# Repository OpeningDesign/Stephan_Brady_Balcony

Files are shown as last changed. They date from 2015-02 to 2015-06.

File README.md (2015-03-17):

Project
==============

Stephan Brady - New Balcony

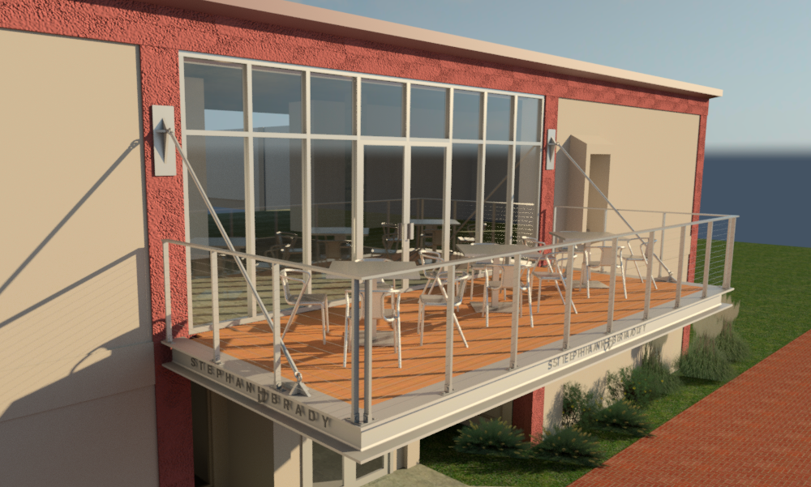
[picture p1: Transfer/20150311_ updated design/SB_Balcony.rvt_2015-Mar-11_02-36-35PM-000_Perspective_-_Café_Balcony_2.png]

============
####In-the-Open

All of [OpeningDesign's](http://openingdesign.com/) projects are conducted out in the open.  That is, during the development of any one project, all team communication and content is hosted [publicly](https://github.com/OpeningDesign) (here on GitHub) and is <a href="#license">open source</a>.

Our [about page](http://openingdesign.com/about/) provides a more nuanced description of this open approach.

============
####License
Per usual, unless otherwise noted, all content associated with [OpeningDesign](http://openingdesign.com) projects is licensed under an open source, 'copyleft' license: 
[Attribution-ShareAlike 4.0 International (CC BY-SA 4.0)](https://creativecommons.org/licenses/by-sa/4.0/).  Attribution to be given to the entire team associated with the project.


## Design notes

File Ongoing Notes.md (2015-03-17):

- (2.27)perforated metal under deck
- (2.27)eliminate under-slung beam
- (2.27)railing to have top cap
- (2.27)decking - angled potentially
- (2.27)lighting
- (2.27)signage
-

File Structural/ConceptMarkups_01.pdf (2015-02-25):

# ntrive

BALCONY | 2015051 SRU | 2/25/15

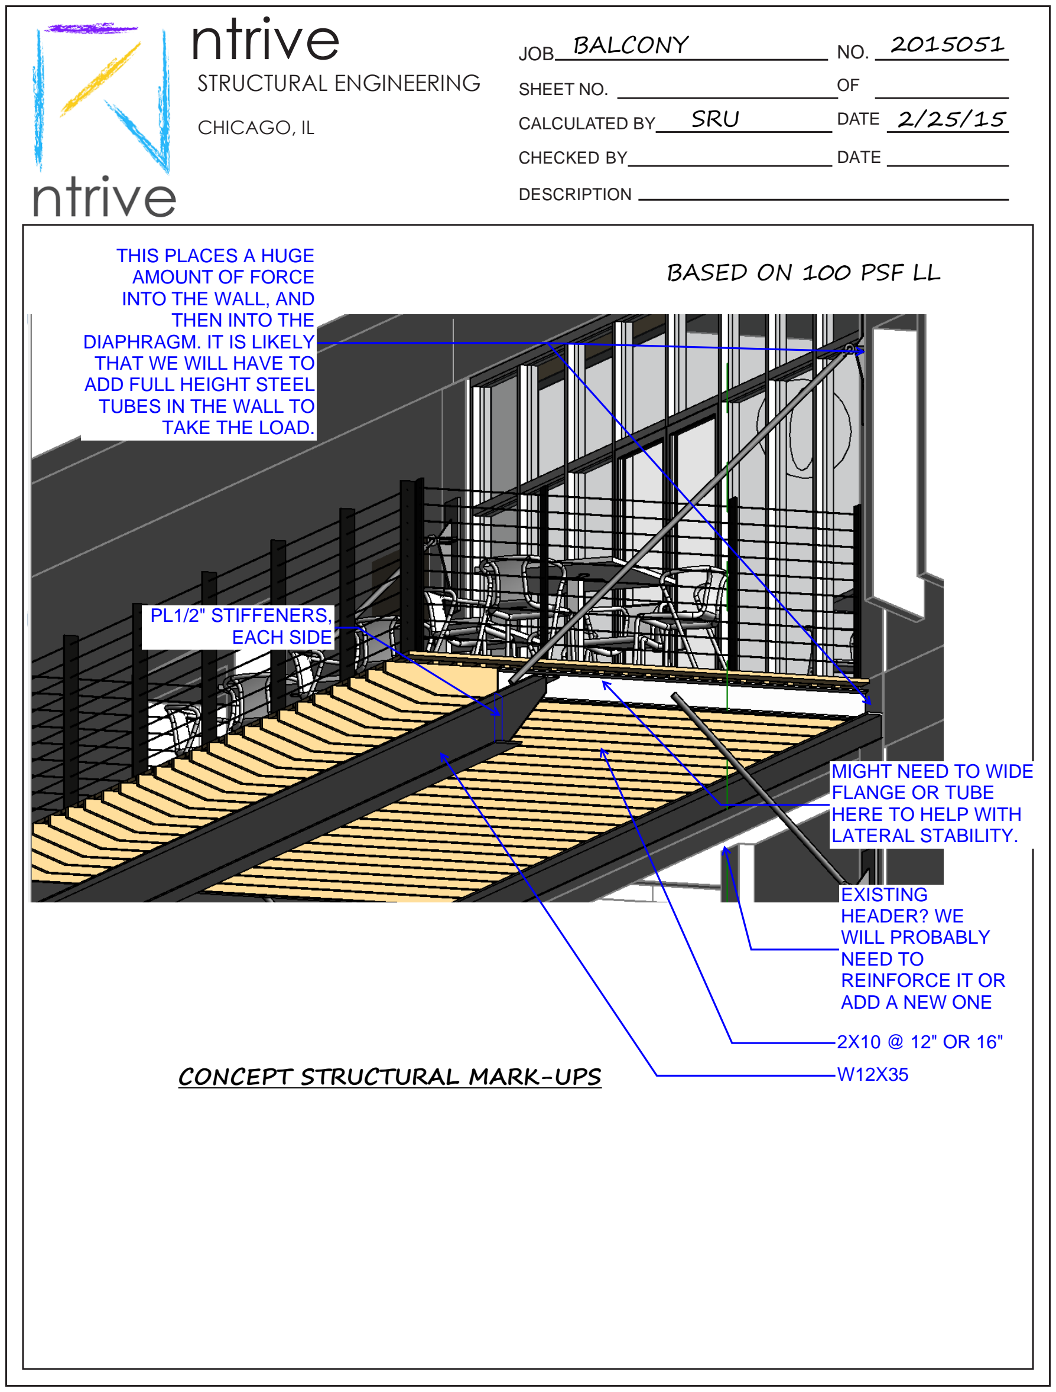
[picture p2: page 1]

STRUCTURAL ENGINEERING

CHICAGO, IL

CHECKED BY

DESCRIPTION

NO.

OF

DATE

DATE

JOB

SHEET NO.

CALCULATED BY

2X10 @ 12" OR 16" W12X35

PL1/2" STIFFENERS,
EACH SIDE

EXISTING
HEADER? WE
WILL PROBABLY
NEED TO
REINFORCE IT OR
ADD A NEW ONE

THIS PLACES A HUGE
AMOUNT OF FORCE
INTO THE WALL, AND
THEN INTO THE
DIAPHRAGM. IT IS LIKELY
THAT WE WILL HAVE TO
ADD FULL HEIGHT STEEL
TUBES IN THE WALL TO
TAKE THE LOAD.

# CONCEPT STRUCTURAL MARK-UPS

MIGHT NEED TO WIDE
FLANGE OR TUBE
HERE TO HELP WITH

LATERAL STABILITY. BASED ON 100 PSF LL

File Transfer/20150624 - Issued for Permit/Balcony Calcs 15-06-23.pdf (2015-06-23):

# Stephan & Brady Balcony

# 1850 Hoffman St

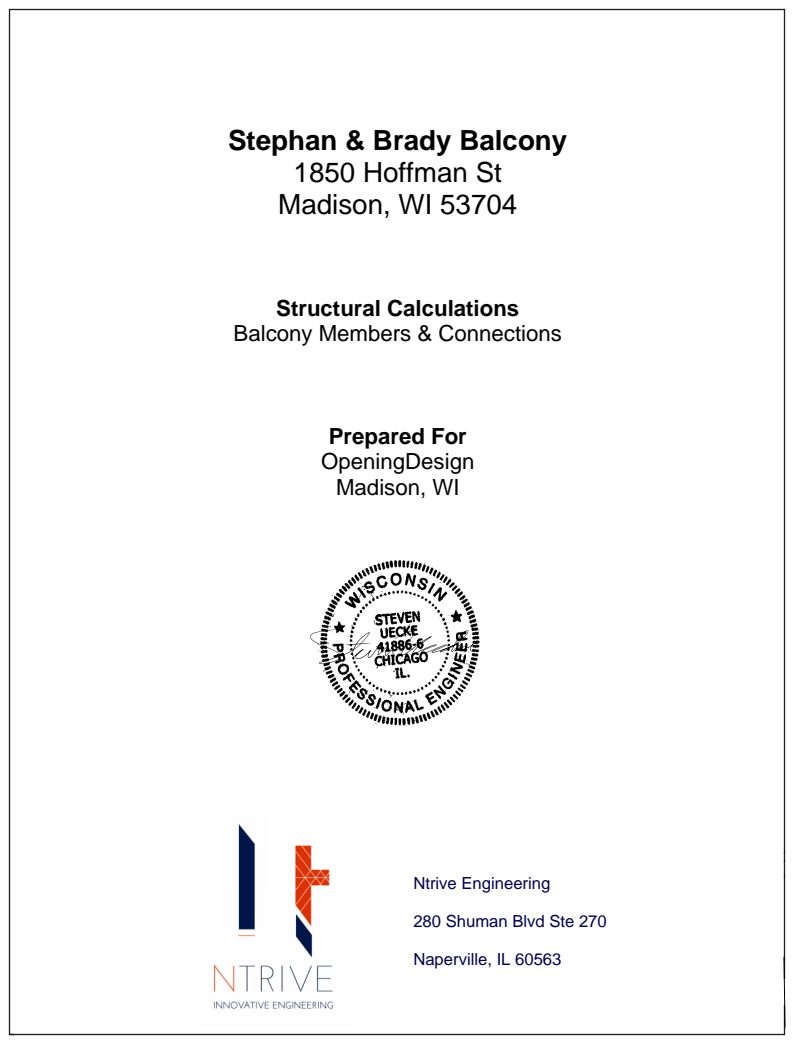
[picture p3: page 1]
Madison, WI 53704; Prepared For OpeningDesign Madison, WI

Structural Calculations
Balcony Members & Connections

Ntrive Engineering
280 Shuman Blvd Ste 270
Naperville, IL 60563

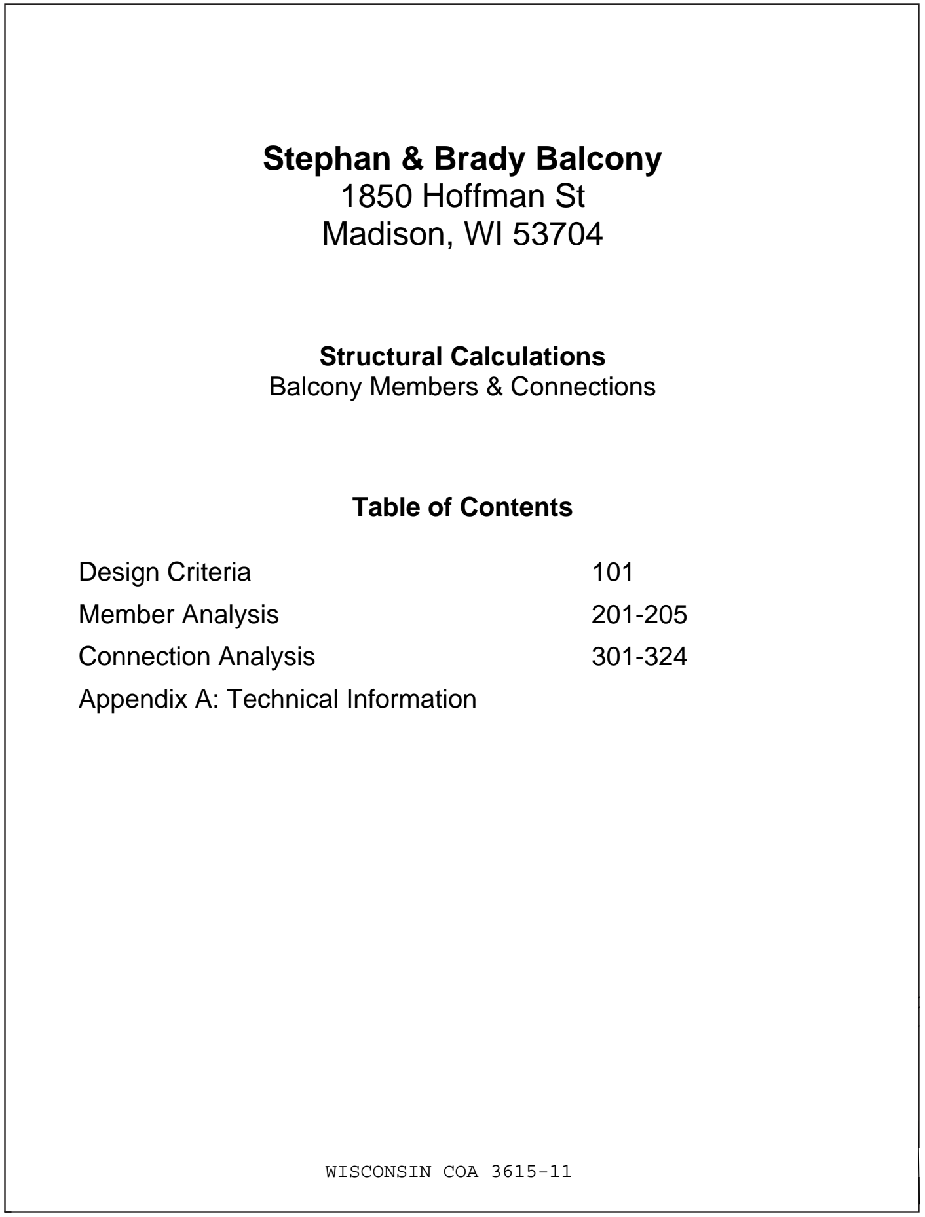
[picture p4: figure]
Stephan & Brady Balcony 1850 Hoffman St Madison, WI 53704; Structural Calculations Balcony Members & Connections; Table of Contents; Design Criteria Member Analysis Connection Analysis Appendix A: Technical Information; WISCONSIN COA 3615-11

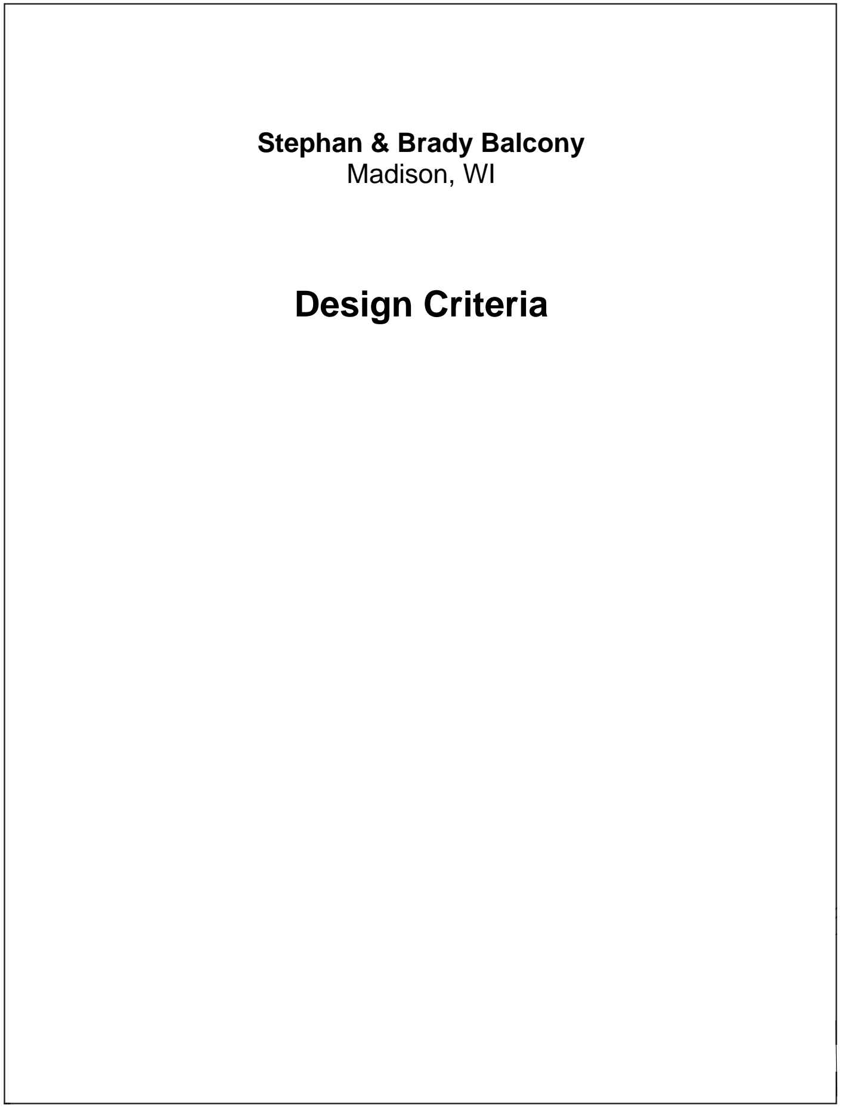
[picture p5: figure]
Stephan & Brady Balcony Madison, WI; Design Criteria

# Ntrive Engineering

# 280 Shuman Blvd Ste 270

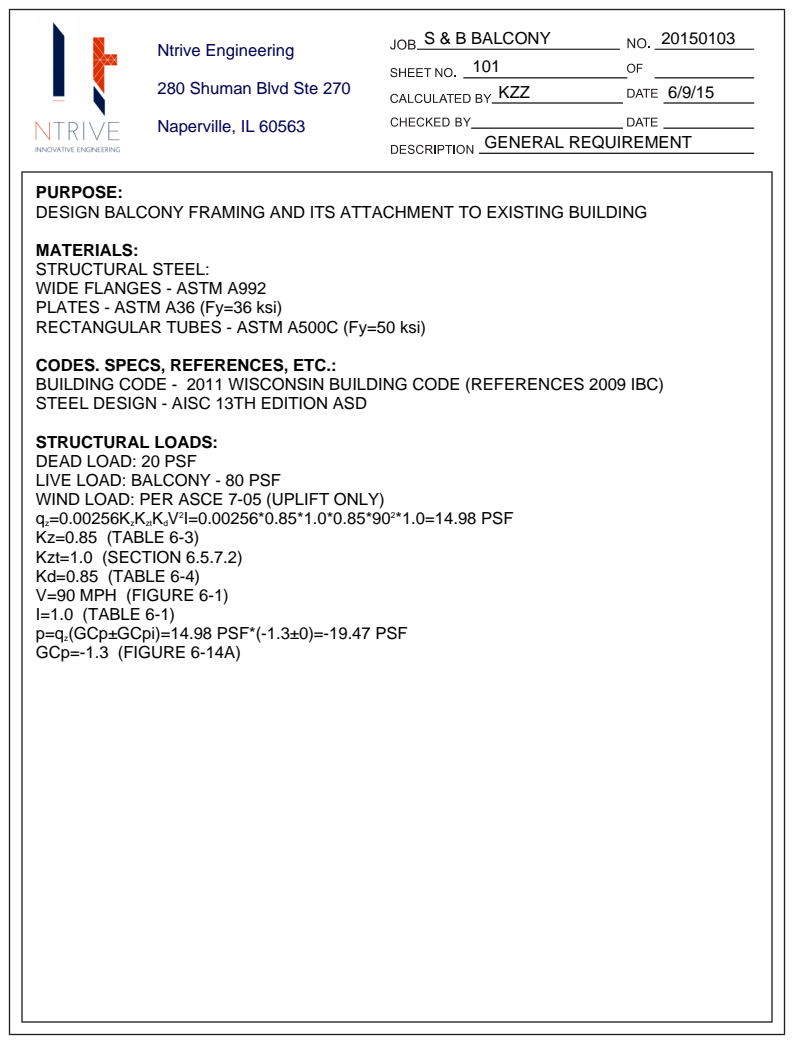
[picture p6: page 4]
Naperville, IL 60563; S & B BALCONY; 20150103 KZZ; 6/9/15 GENERAL REQUIREMENT; *1.0=14.98 PSF

PURPOSE:
DESIGN BALCONY FRAMING AND ITS ATTACHMENT TO EXISTING BUILDING
MATERIALS:
STRUCTURAL STEEL:
WIDE FLANGES - ASTM A992
PLATES - ASTM A36 (Fy=36 ksi)
RECTANGULAR TUBES - ASTM A500C (Fy=50 ksi)
CODES. SPECS, REFERENCES, ETC.:
BUILDING CODE - 2011 WISCONSIN BUILDING CODE (REFERENCES 2009 IBC)
STEEL DESIGN - AISC 13TH EDITION ASD
STRUCTURAL LOADS:
DEAD LOAD: 20 PSF
LIVE LOAD: BALCONY - 80 PSF
WIND LOAD: PER ASCE 7-05 (UPLIFT ONLY)
qz=0.00256KzKztKdV
Kz=0.85 (TABLE 6-3)
Kzt=1.0 (SECTION 6.5.7.2)
Kd=0.85 (TABLE 6-4)
V=90 MPH (FIGURE 6-1)
I=1.0 (TABLE 6-1)
p=qz(GCp±GCpi)=14.98 PSF*(-1.3±0)=-19.47 PSF
GCp=-1.3 (FIGURE 6-14A)

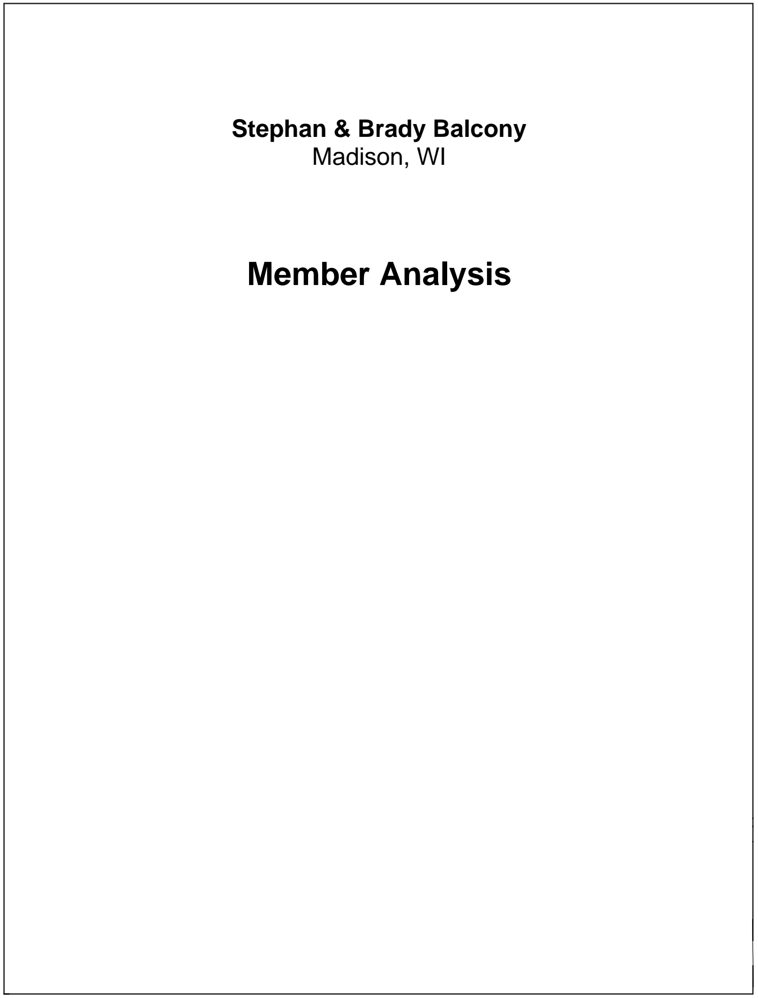
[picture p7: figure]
Stephan & Brady Balcony Madison, WI; Member Analysis

# Ntrive Engineering

# 280 Shuman Blvd Ste 270

PRE-DRILLED GALVANIZED
STEEL (W10X39) W - SECTION

FIRE-RATED LUMBER
SIZE AND O.C. SPACING T.B.D.

COMPOSITE DECKING ABOVE

CHECK BENDING STRENGTH OF WIDE FLANGE BEAM:
Wd=20 PSF*11'/2=110 PLF
Wl=80 PSF*11'/2=440 PLF
Wt=110 PLF+440 PLF=550 PLF
Mact=Wt*L²
Mall=117 FT*K > 30.8 FT*K, OK (AISC TABLE 3-6)
CHECK DEFLECTION OF WIDE FLANGE BEAM:
Δ=(5*Wt*L⁴⁾/(384*E*I)=(5*550 PLF*(21'-2")⁴
Δall=L/240=21'-2"/240=1.058" > 0.409", OK
PROVIDE W10x39

# Ntrive Engineering

# 280 Shuman Blvd Ste 270

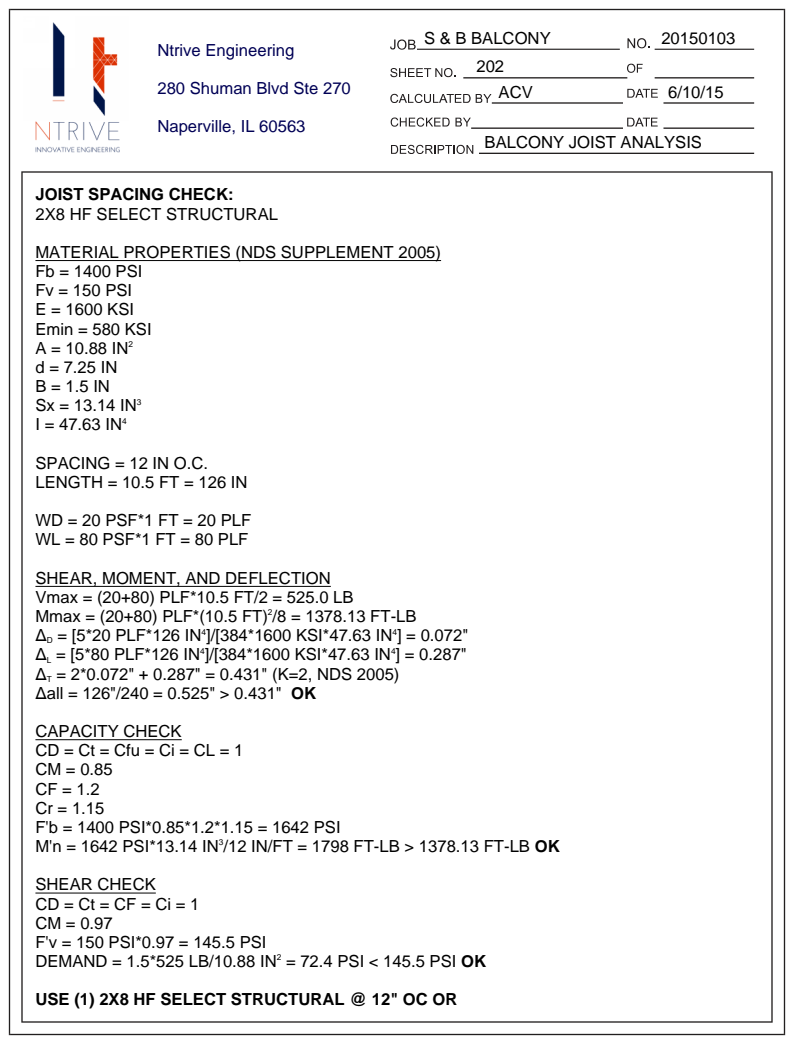
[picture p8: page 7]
Naperville, IL 60563; S & B BALCONY; 20150103 ACV; 6/10/15 BALCONY JOIST ANALYSIS; /8 = 1378.13 FT-LB ]/[384*1600 KSI*47.63 IN⁴; ]/[384*1600 KSI*47.63 IN⁴

USE (1) 2X8 HF SELECT STRUCTURAL @ 12" OC OR 202

JOIST SPACING CHECK:
2X8 HF SELECT STRUCTURAL

MATERIAL PROPERTIES (NDS SUPPLEMENT 2005)
Fb = 1400 PSI
Fv = 150 PSI
E = 1600 KSI
Emin = 580 KSI
A = 10.88 IN²
Sx = 13.14 IN³
I = 47.63 IN⁴

SPACING = 12 IN O.C.
LENGTH = 10.5 FT = 126 IN

WD = 20 PSF*1 FT = 20 PLF
WL = 80 PSF*1 FT = 80 PLF

SHEAR, MOMENT, AND DEFLECTION
Vmax = (20+80) PLF*10.5 FT/2 = 525.0 LB
Mmax = (20+80) PLF*(10.5 FT)²
ΔD = [5*20 PLF*126 IN⁴
ΔL = [5*80 PLF*126 IN⁴
ΔT = 2*0.072" + 0.287" = 0.431" (K=2, NDS 2005)
Δall = 126"/240 = 0.525" > 0.431" OK

CAPACITY CHECK
CD = Ct = Cfu = Ci = CL = 1
F'b = 1400 PSI*0.85*1.2*1.15 = 1642 PSI
M'n = 1642 PSI*13.14 IN³

SHEAR CHECK
F'v = 150 PSI*0.97 = 145.5 PSI
DEMAND = 1.5*525 LB/10.88 IN²

= 72.4 PSI < 145.5 PSI OK

# Ntrive Engineering

# 280 Shuman Blvd Ste 270

JOIST SPACING CHECK:

MATERIAL PROPERTIES (NDS SUPPLEMENT 2005)
Fb = 850 PSI
Fv = 150 PSI
E = 1300 KSI
Emin = 470 KSI
A = 10.88 IN²
Sx = 13.14 IN³
I = 47.63 IN⁴

SPACING = 12 IN O.C.
LENGTH = 10.5 FT = 126 IN

WD = 20 PSF*1 FT = 20 PLF
WL = 80 PSF*1 FT = 80 PLF

SHEAR, MOMENT, AND DEFLECTION
Vmax = (20+80) PLF*10.5 FT/2 = 525.0 LB
Mmax = (20+80) PLF*(10.5 FT)²
ΔD = [5*20 PLF*126 IN⁴
ΔL = [5*80 PLF*126 IN⁴
ΔT = (2*0.088" + 0.353")/2 = 0.265" (K=2, NDS 2005)
Δall = 126"/240 = 0.525" > 0.265" OK

CAPACITY CHECK
CD = CM = Ct = Cfu = Ci = CL = 1
F'b = 850 PSI*1.2*1.15 = 1173 PSI
M'n = 2*1173 PSI*13.14 IN³

SHEAR CHECK
F'v = 150 PSI*0.97 = 145.5 PSI
DEMAND = 1.5*525 LB/2*10.88 IN²
USE (2) 2X8 HF NO.2 OR BETTER @ 12" OC

= 36.2 PSI < 145.5 PSI OK

# Ntrive Engineering

# 280 Shuman Blvd Ste 270

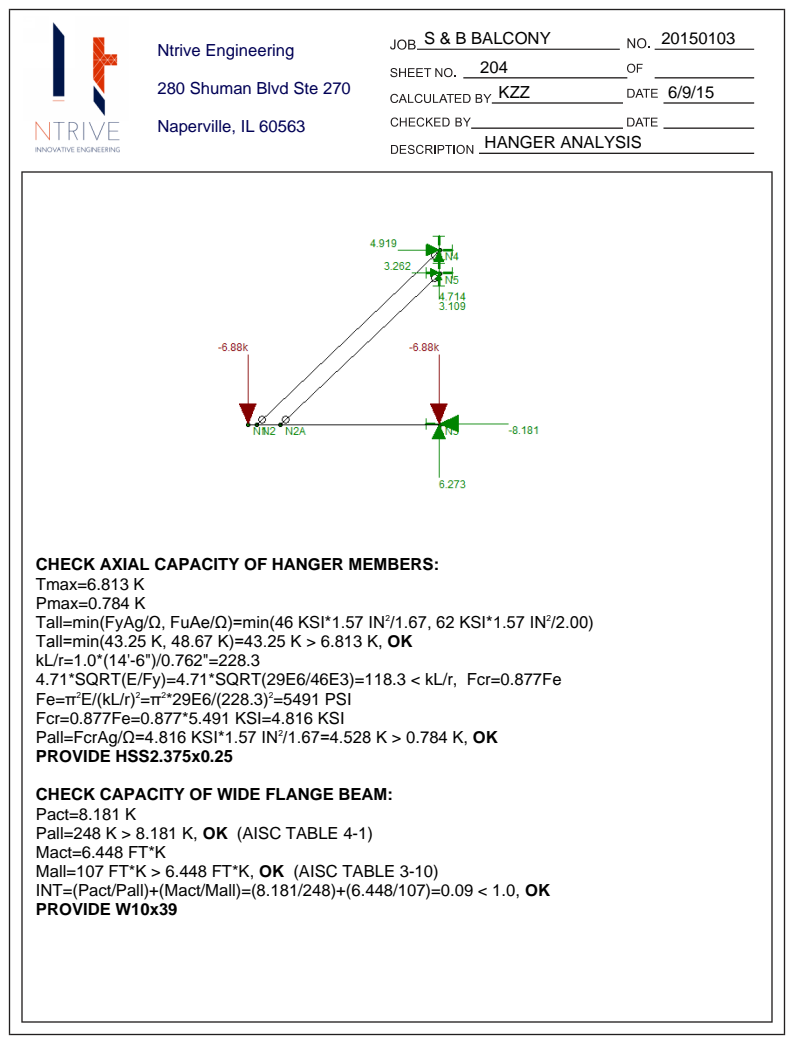
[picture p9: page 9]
Naperville, IL 60563; S & B BALCONY; 20150103 KZZ; 6/9/15 HANGER ANALYSIS; /1.67, 62 KSI*1.57 IN²; *29E6/(228.3)²=5491 PSI

CHECK AXIAL CAPACITY OF HANGER MEMBERS:
Tmax=6.813 K
Pmax=0.784 K
Tall=min(FyAg/Ω, FuAe/Ω)=min(46 KSI*1.57 IN²
Tall=min(43.25 K, 48.67 K)=43.25 K > 6.813 K, OK
4.71*SQRT(E/Fy)=4.71*SQRT(29E6/46E3)=118.3 < kL/r, Fcr=0.877Fe
Fcr=0.877Fe=0.877*5.491 KSI=4.816 KSI
Pall=FcrAg/Ω=4.816 KSI*1.57 IN²
PROVIDE HSS2.375x0.25
CHECK CAPACITY OF WIDE FLANGE BEAM:
Pact=8.181 K
Pall=248 K > 8.181 K, OK (AISC TABLE 4-1)
Mact=6.448 FT*K
Mall=107 FT*K > 6.448 FT*K, OK (AISC TABLE 3-10)
INT=(Pact/Pall)+(Mact/Mall)=(8.181/248)+(6.448/107)=0.09 < 1.0, OK
PROVIDE W10x39

# Ntrive Engineering

# 280 Shuman Blvd Ste 270

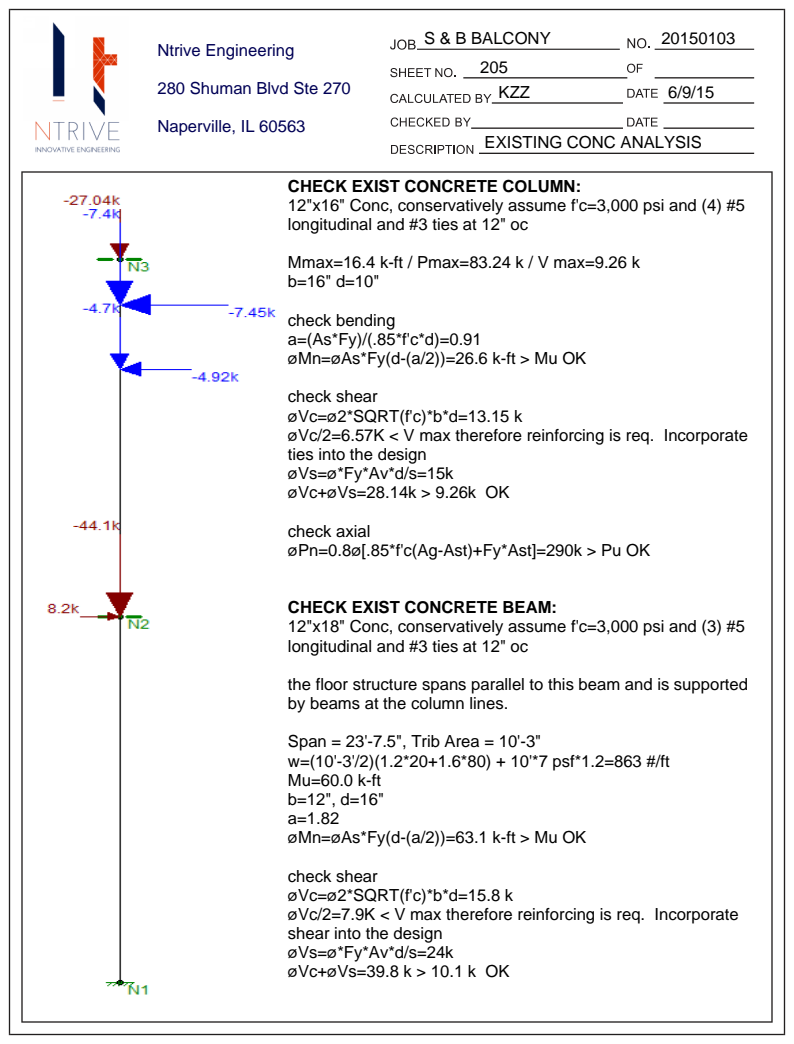
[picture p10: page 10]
Naperville, IL 60563; S & B BALCONY; 20150103 KZZ; 6/9/15 EXISTING CONC ANALYSIS

CHECK EXIST CONCRETE COLUMN:
12"x16" Conc, conservatively assume f'c=3,000 psi and (4) #5
longitudinal and #3 ties at 12" oc
Mmax=16.4 k-ft / Pmax=83.24 k / V max=9.26 k
check bending
øMn=øAs*Fy(d-(a/2))=26.6 k-ft > Mu OK
check shear
øVc=ø2*SQRT(f'c)*b*d=13.15 k
øVc/2=6.57K < V max therefore reinforcing is req. Incorporate
ties into the design
øVs=ø*Fy*Av*d/s=15k
øVc+øVs=28.14k > 9.26k OK
check axial
øPn=0.8ø[.85*f'c(Ag-Ast)+Fy*Ast]=290k > Pu OK

CHECK EXIST CONCRETE BEAM:
12"x18" Conc, conservatively assume f'c=3,000 psi and (3) #5
the floor structure spans parallel to this beam and is supported
by beams at the column lines.
Span = 23'-7.5", Trib Area = 10'-3"
w=(10'-3'/2)(1.2*20+1.6*80) + 10'*7 psf*1.2=863 #/ft
øMn=øAs*Fy(d-(a/2))=63.1 k-ft > Mu OK
øVc=ø2*SQRT(f'c)*b*d=15.8 k
øVc/2=7.9K < V max therefore reinforcing is req. Incorporate
shear into the design
øVs=ø*Fy*Av*d/s=24k
øVc+øVs=39.8 k > 10.1 k OK

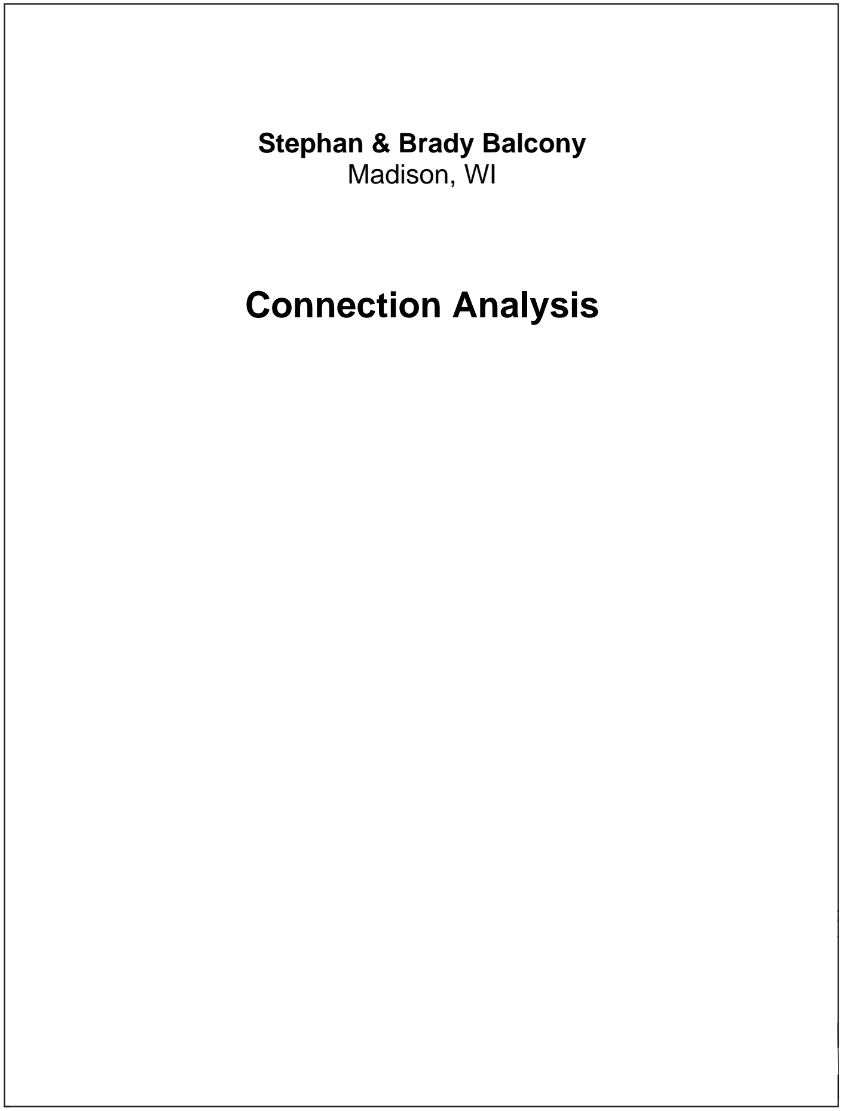
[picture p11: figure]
Stephan & Brady Balcony Madison, WI; Connection Analysis

# Ntrive Engineering

# 280 Shuman Blvd Ste 270

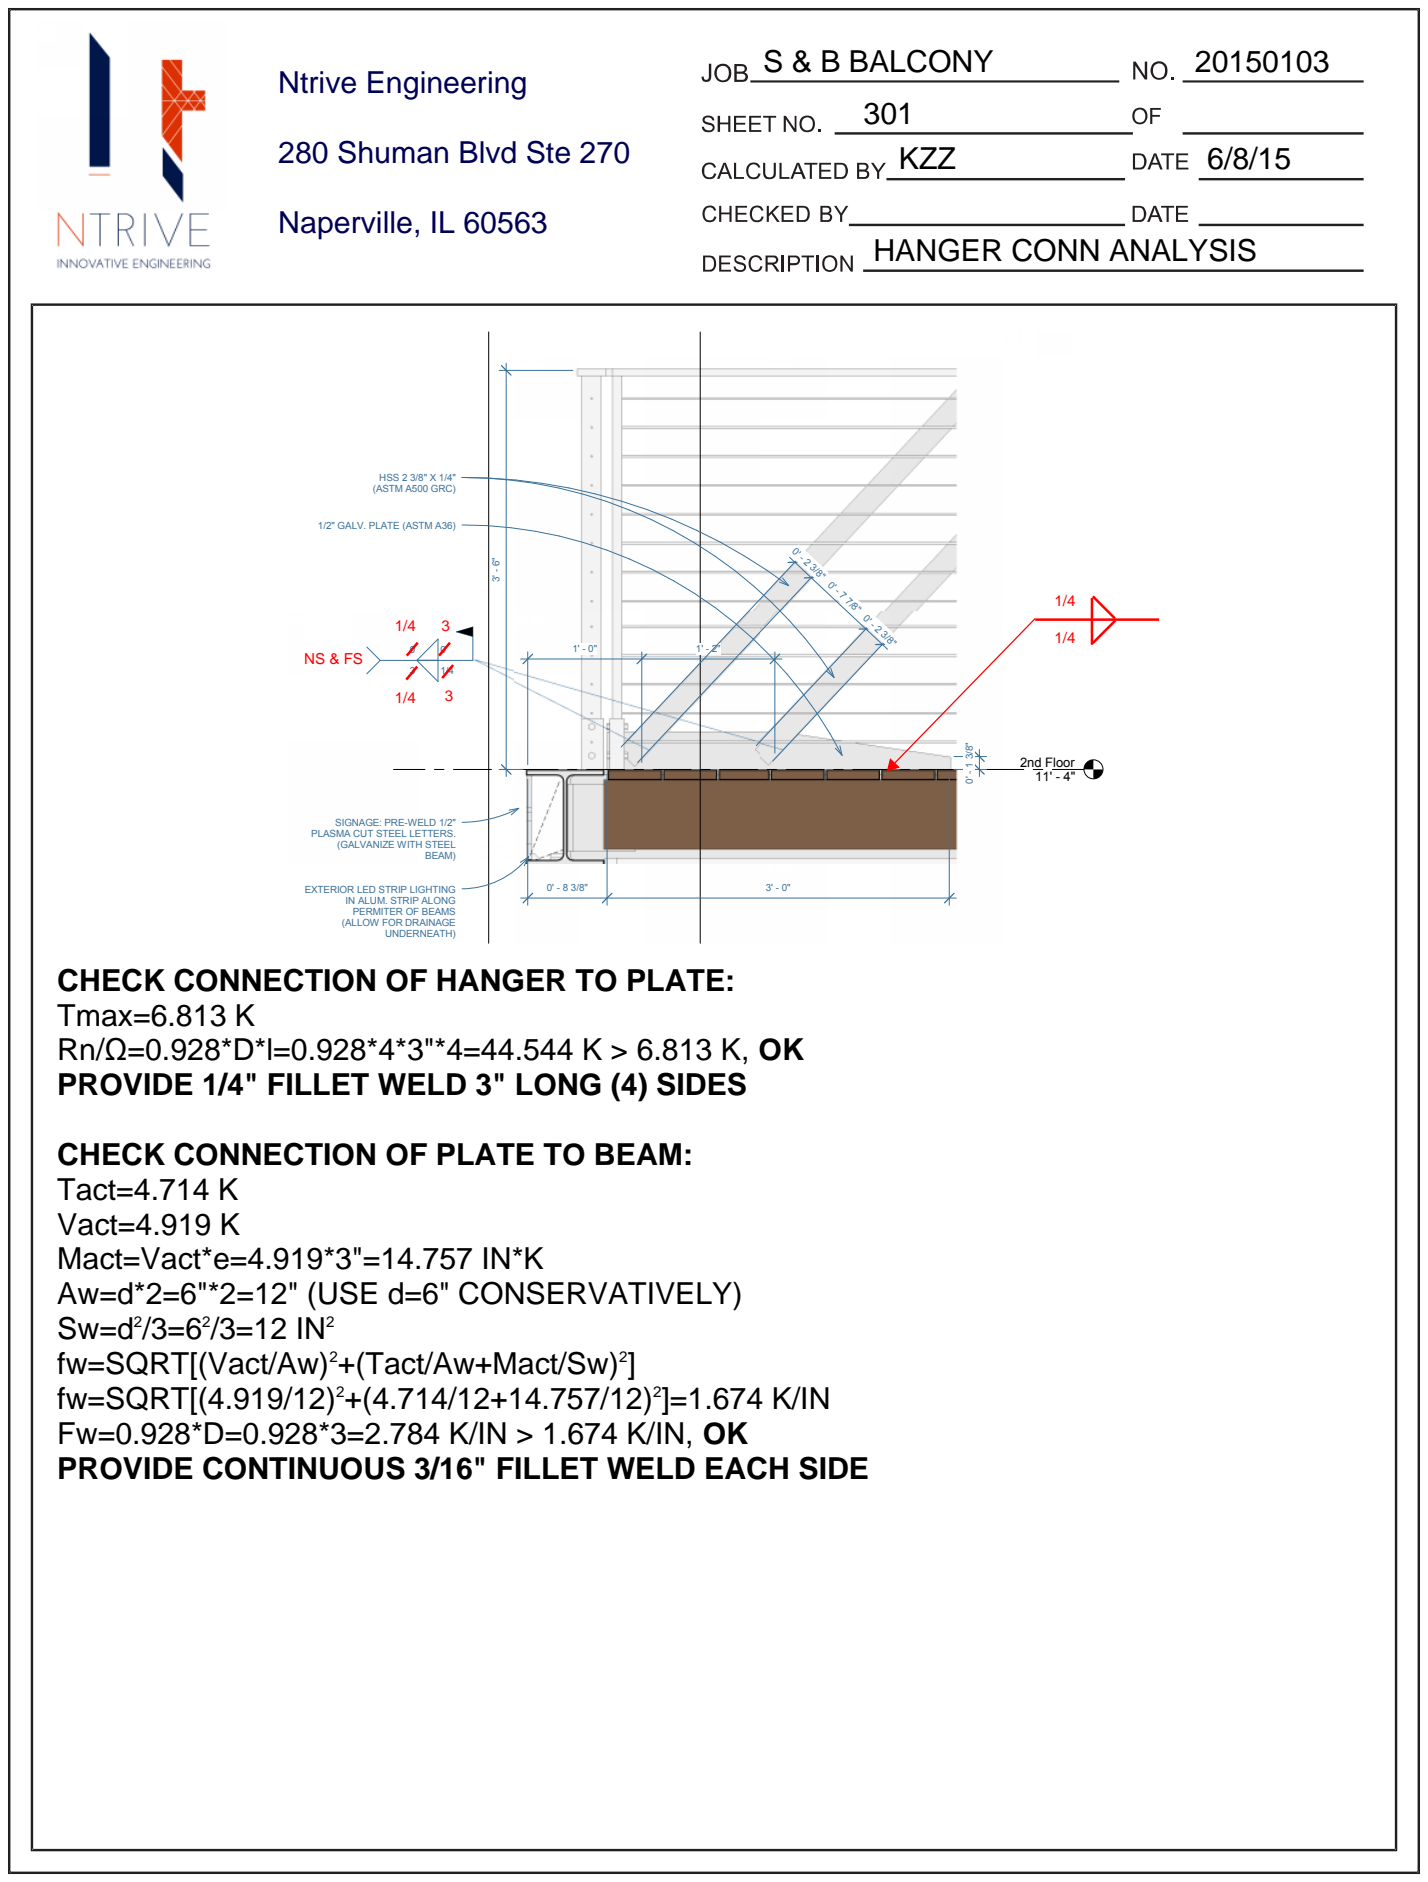
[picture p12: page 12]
Naperville, IL 60563; S & B BALCONY; 20150103 KZZ; 6/8/15 HANGER CONN ANALYSIS; /3=12 IN²; 2nd Floor 11' - 4"; HSS 2 3/8" X 1/4" (ASTM A500 GRC)

1/2" GALV. PLATE (ASTM A36)

SIGNAGE: PRE-WELD 1/2" PLASMA CUT STEEL LETTERS.

(GALVANIZE WITH STEEL BEAM)

EXTERIOR LED STRIP LIGHTING

IN ALUM. STRIP ALONG
PERMITER OF BEAMS
(ALLOW FOR DRAINAGE UNDERNEATH)

CHECK CONNECTION OF HANGER TO PLATE:
Tmax=6.813 K
PROVIDE 1/4" FILLET WELD 3" LONG (4) SIDES
CHECK CONNECTION OF PLATE TO BEAM:
Tact=4.714 K
Vact=4.919 K
Mact=Vact*e=4.919*3"=14.757 IN*K
Aw=d*2=6"*2=12" (USE d=6" CONSERVATIVELY)
fw=SQRT[(Vact/Aw)²+(Tact/Aw+Mact/Sw)²
fw=SQRT[(4.919/12)²+(4.714/12+14.757/12)²
PROVIDE CONTINUOUS 3/16" FILLET WELD EACH SIDE

# Ntrive Engineering

# 280 Shuman Blvd Ste 270

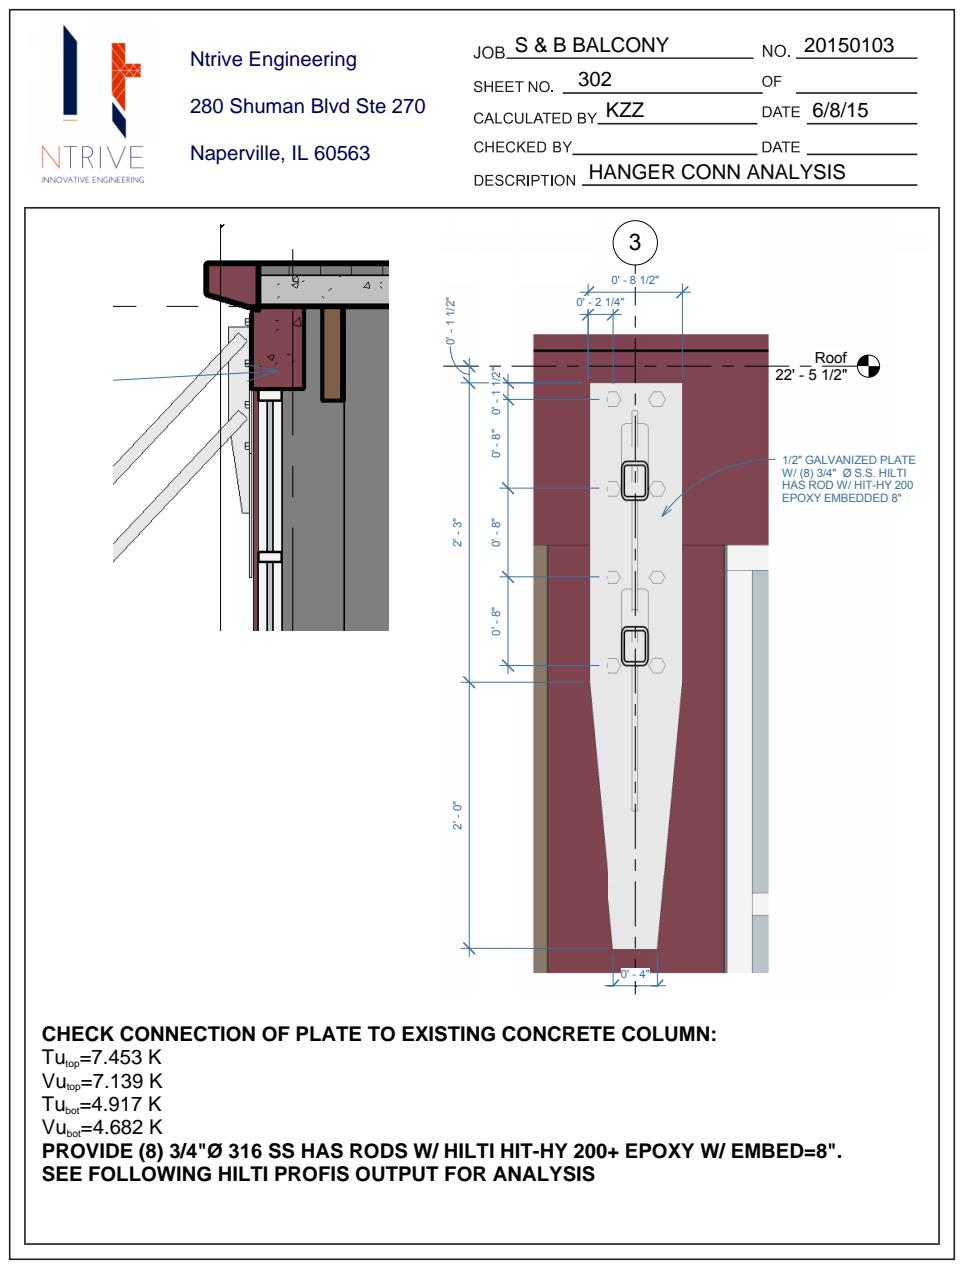
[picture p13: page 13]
Naperville, IL 60563; S & B BALCONY; 20150103 KZZ; 6/8/15 HANGER CONN ANALYSIS; Roof 22' - 5 1/2"

1/2" GALVANIZED PLATE
W/ (8) 3/4" Ø S.S. HILTI
HAS ROD W/ HIT-HY 200
EPOXY EMBEDDED 8"

CHECK CONNECTION OF PLATE TO EXISTING CONCRETE COLUMN:
Tutop=7.453 K
Vutop=7.139 K
Tubot=4.917 K
Vubot=4.682 K
PROVIDE (8) 3/4"Ø 316 SS HAS RODS W/ HILTI HIT-HY 200+ EPOXY W/ EMBED=8".
SEE FOLLOWING HILTI PROFIS OUTPUT FOR ANALYSIS

www.hilti.us | Profis Anchor 2.5.3

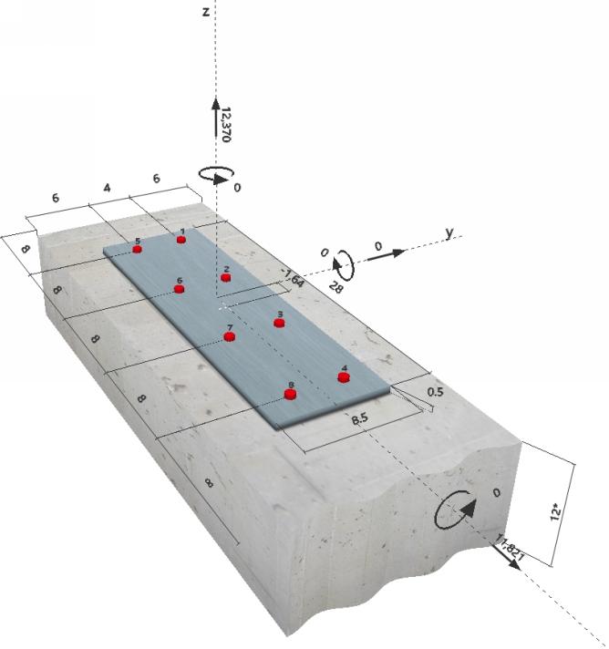
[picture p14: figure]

Input data and results must be checked for agreement with the existing conditions and for plausibility!
PROFIS Anchor ( c ) 2003-2009 Hilti AG, FL-9494 Schaan Hilti is a registered Trademark of Hilti AG, Schaan

Company:
Specifier:
Address:
Phone I Fax:
E-Mail:

Ntrive
KZZ

Page:
Project:
Sub-Project I Pos. No.:
Date:

1
20150103

6/8/2015

Specifier's comments:

## 1 Input data

Anchor type and diameter: | HIT-HY 200 + HAS-R 316 3/4
Effective embedment depth: | hef,act = 8.000 in. (hef,limit = - in.)
Material: | ASTM F 593
Evaluation Service Report: | ESR-3187
Issued I Valid: | 1/1/2015 | 3/1/2016
Proof: | Design method ACI 318-08 / Chem
Stand-off installation: | eb = 0.000 in. (no stand-off); t = 0.500 in.
Anchor plate: | lx x ly x t = 28.000 in. x 8.500 in. x 0.500 in.; (Recommended plate thickness: not calculated)
Profile: | no profile
Base material: | cracked concrete, , fc ' = 3500 psi; h = 12.000 in., Temp. short/long: 32/32 °F
Installation: | hammer drilled hole, Installation condition: Dry
Reinforcement: | tension: condition B, shear: condition B; no supplemental splitting reinforcement present
| edge reinforcement: none or < No. 4 bar
Seismic loads (cat. C, D, E, or F) | no

Geometry [in.] & Loading [lb, in.lb]

Company:
Specifier:
Address:
Phone I Fax:
E-Mail:

Ntrive
KZZ

Page:
Project:
Sub-Project I Pos. No.:
Date:

2
20150103

6/8/2015

## 2 Load case/Resulting anchor forces

Load case: Design loads

Anchor reactions [lb]
Tension force: (+Tension, -Compression)
Anchor | Tension force | Shear force | Shear force x | Shear force y
1 | 1927 | 1478 | 1478 | 0
2 | 1673 | 1478 | 1478 | 0
3 | 1419 | 1478 | 1478 | 0
4 | 1166 | 1478 | 1478 | 0
5 | 1927 | 1478 | 1478 | 0
6 | 1673 | 1478 | 1478 | 0
7 | 1419 | 1478 | 1478 | 0
8 | 1166 | 1478 | 1478 | 0
max. concrete compressive strain: | - [‰]
max. concrete compressive stress: | - [psi]
resulting tension force in (x/y)=(-1.640/0.000): | 12370 [lb]
resulting compression force in (x/y)=(0.000/0.000): 0 [lb]

Tension

1 | 2 | 3 | 4
5 | 6 | 7 | 8

x

y

## 3 Tension load

| Load Nua [lb] | Capacity fNn [lb] | Utilization bN = Nua/fNn | Status
Steel Strength* | 1927 | 18479 | 11 | OK
Bond Strength** | 12370 | 17184 | 72 | OK
Sustained Tension Load Bond Strength* | N/A | N/A | N/A | N/A
Concrete Breakout Strength** | 12370 | 15452 | 81 | OK
* anchor having the highest loading **anchor group (anchors in tension)

### 3.1 Steel Strength

Nsa | = ESR value | refer to ICC-ES ESR-3187
f Nsteel | Nua | ACI 318-08 Eq. (D-1)

Variables
n | Ase,N [in.²
] | futa [psi]
1 | 0.33 | 85000
Calculations
Nsa [lb]
28430
Results
Nsa [lb] | fsteel | f Nsa [lb] | Nua [lb]
28430 | 0.650 | 18479 | 1927

Company:
Specifier:
Address:
Phone I Fax:
E-Mail:

Ntrive
KZZ

Page:
Project:
Sub-Project I Pos. No.:
Date:

3
20150103

6/8/2015

### 3.2 Bond Strength

Nag = (
ANa
ANa0) yec1,Na yec2,Na yed,Na ycp,Na Nba | ACI 318-11 Eq. (D-19)
f Nag | Nua | ACI 318-11 Table D.4.1.1
ANa | = see ACI 318-11, Part D.5.5.1, Fig. RD.5.5.1(b)

ANa0 = (2 cNa)

2
ACI 318-11 Eq. (D-20)
cNa = 10 da

tuncr
1100 | ACI 318-11 Eq. (D-21)

yec,Na = (
1
1 + e

'
N
cNa

)
1.0 | ACI 318-11 Eq. (D-23)

yed,Na = 0.7 + 0.3 (
ca,min
| cNa ) 1.0 | | ACI 318-11 Eq. (D-25)

ycp,Na = MAX(
ca,min
cac

,

cNa
cac
| ) 1.0 | | ACI 318-11 Eq. (D-27)
Nba | = la
- tk,c · kbond · p · da
| · hef | | ACI 318-11 Eq. (D-22)

Variables

tk,c,uncr [psi] | da
| [in.] | hef [in.] | ca,min [in.] | tk,c [psi]
1727 | 0.750 | 8.000 | 6.000 | 977
ec1,N [in.] | ec2,N [in.] | cac [in.] | kbond | la
1.640 | 0.000 | 19.129 | 1.00 | 1.000
Calculations
cNa [in.] | ANa [in.²
| ] | ANa0 [in.²
] | yed,Na
9.355 | 661.69 | 350.10 | 0.892
yec1,Na | yec2,Na | ycp,Na | Nba [lb]
0.851 | 1.000 | 1.000 | 18422
Results
Nag [lb] | fbond | f Nag [lb] | Nua [lb]
26438 | 0.650 | 17184 | 12370

Company:
Specifier:
Address:
Phone I Fax:
E-Mail:

Ntrive
KZZ

Page:
Project:
Sub-Project I Pos. No.:
Date:

4
20150103

6/8/2015

### 3.3 Concrete Breakout Strength

Ncbg = (
ANc

ANc0) yec,N yed,N yc,N ycp,N Nb
ACI 318-08 Eq. (D-5)
f Ncbg | Nua | ACI 318-08 Eq. (D-1)
ANc | see ACI 318-08, Part D.5.2.1, Fig. RD.5.2.1(b)
ANc0 | = 9 h²
| ef | ACI 318-08 Eq. (D-6)
yec,N = (
1
| 1 + 2 e'
N
3 hef

)
1.0 | ACI 318-08 Eq. (D-9)

yed,N = 0.7 + 0.3 (
ca,min
| 1.5hef) 1.0 | | ACI 318-08 Eq. (D-11)

ycp,N = MAX(
ca,min
cac

,

| 1.5hef
cac
| ) 1.0 | | ACI 318-08 Eq. (D-13)
Nb | = kc l f

'
c

h¹.5
ef | ACI 318-08 Eq. (D-7)

Variables
hef [in.] | ec1,N [in.] | ec2,N [in.] | ca,min [in.] | yc,N
5.333 | 1.640 | 0.000 | 6.000 | 1.000
cac [in.] | kc | l | f ' c [psi]
19.129 | 17 | 1 | 3500

Calculations
ANc [in.²
] | ANc0 [in.²
] | yec1,N | yec2,N | yed,N | ycp,N | Nb
| | | | | | [lb]
640.00 | 256.00 | 0.830 | 1.000 | 0.925 | 1.000 | 12387
Results
Ncbg [lb] | fconcrete | f Ncbg [lb] | Nua [lb]
23773 | 0.650 | 15452 | 12370

Company:
Specifier:
Address:
Phone I Fax:
E-Mail:

Ntrive
KZZ

Page:
Project:
Sub-Project I Pos. No.:
Date:

5
20150103

6/8/2015

## 4 Shear load

| Load Vua [lb] | Capacity fVn [lb] | Utilization bV = Vua/fVn | Status
Steel Strength* | 1478 | 10236 | 15 | OK
Steel failure (with lever arm)* | N/A | N/A | N/A | N/A
Pryout Strength (Concrete Breakout Strength controls)** | 11821 | 40104 | 30 | OK
Concrete edge failure in direction y+** | 11821 | 25477 | 47 | OK
* anchor having the highest loading **anchor group (relevant anchors)

### 4.1 Steel Strength

Vsa | = (n 0.6 Ase,V futa) | refer to ICC-ES ESR-3187
f Vsteel | Vua | ACI 318-08 Eq. (D-2)

Variables
n | Ase,V [in.²
] | futa [psi] | (n 0.6 Ase,V futa) [lb]
1 | 0.33 | 85000 | 17060
Calculations
Vsa [lb]
17060
Results
Vsa [lb] | fsteel | f Vsa [lb] | Vua [lb]
17060 | 0.600 | 10236 | 1478

### 4.2 Pryout Strength (Concrete Breakout Strength controls)

Vcpg = kcp [(
ANc

ANc0) yec,N yed,N yc,N ycp,N Nb]
ACI 318-08 Eq. (D-31)
f Vcpg | Vua | ACI 318-08 Eq. (D-2)
ANc | see ACI 318-08, Part D.5.2.1, Fig. RD.5.2.1(b)
ANc0 | = 9 h²
ef | ACI 318-08 Eq. (D-6)
yec,N = (
1
| 1 + 2 e'
N
3 hef

)
1.0 | ACI 318-08 Eq. (D-9)

yed,N = 0.7 + 0.3 (
ca,min
| 1.5hef) 1.0 | | ACI 318-08 Eq. (D-11)

ycp,N = MAX(
ca,min
cac

,

1.5hef
cac
| ) 1.0 | | ACI 318-08 Eq. (D-13)
Nb | = kc l f

'
c

h¹.5
ef | ACI 318-08 Eq. (D-7)

Variables
kcp | hef [in.] | ec1,N [in.] | ec2,N [in.] | ca,min [in.]
2 | 5.333 | 0.000 | 0.000 | 6.000
yc,N | cac [in.] | kc | l | f ' c [psi]
1.000 | 19.129 | 17 | 1 | 3500

Calculations
ANc [in.²
] | ANc0 [in.²
] | yec1,N | yec2,N | yed,N | ycp,N | Nb
| | | | | | [lb]
640.00 | 256.00 | 1.000 | 1.000 | 0.925 | 1.000 | 12387
Results
Vcpg [lb] | fconcrete | f Vcpg [lb] | Vua [lb]
57292 | 0.700 | 40104 | 11821

Company:
Specifier:
Address:
Phone I Fax:
E-Mail:

Ntrive
KZZ

Page:
Project:
Sub-Project I Pos. No.:
Date:

6
20150103

6/8/2015

### 4.3 Concrete edge failure in direction y+

Vcbg = (
AVc

AVc0) yec,V yed,V yc,V yh,V yparallel,V Vb
ACI 318-08 Eq. (D-22)
f Vcbg | Vua | ACI 318-08 Eq. (D-2)
AVc | see ACI 318-08, Part D.6.2.1, Fig. RD.6.2.1(b)
AVc0 | = 4.5 c²
a1 | ACI 318-08 Eq. (D-23)
yec,V = (
1
| 1 + 2e'
v
3ca1

)
1.0 | ACI 318-08 Eq. (D-26)

yed,V = 0.7 + 0.3(
ca2
1.5ca1) 1.0 | ACI 318-08 Eq. (D-28)
yh,V | =

1.5ca1
ha
1.0 | ACI 318-08 Eq. (D-29)
Vb | = (7 (
le
da

)

0.2

da) l f
'
c

c¹.5
| a1 | | ACI 318-08 Eq. (D-24)

Variables
ca1 [in.] | ca2 [in.] | ecV [in.] | yc,V | ha [in.]
6.000 | 8.000 | 0.000 | 1.000 | 12.000

le

[in.] | l | da
| | [in.] | f '
| | | c
| | | [psi] | yparallel,V
6.000 | 1.000 | 0.750 | 3500 | 2.000

Calculations
AVc [in.²
] | AVc0 [in.²
] | yec,V | yed,V | yh,V | Vb
| | | | | [lb]
369.00 | 162.00 | 1.000 | 1.000 | 1.000 | 7989
Results
Vcbg [lb] | fconcrete | f Vcbg [lb] | Vua [lb]
36396 | 0.700 | 25477 | 11821

## 5 Combined tension and shear loads

bN | bV | z | Utilization bN,V [%] | Status
0.801 | 0.464 | 5/3 | 97 | OK
bNV = b

z
N + b

z
V <= 1

## 6 Warnings

- Load re-distributions on the anchors due to elastic deformations of the anchor plate are not considered. The anchor plate is assumed to be sufficiently stiff, in order not to be deformed when subjected to the loading!

Input data and results must be checked for agreement with the existing conditions and for plausibility!
- Condition A applies when supplementary reinforcement is used. The factor is increased for non-steel Design Strengths except Pullout Strength and Pryout strength. Condition B applies when supplementary reinforcement is not used and for Pullout Strength and Pryout Strength. Refer to your local standard.
- Design Strengths of adhesive anchor systems are influenced by the cleaning method. Refer to the INSTRUCTIONS FOR USE given in the Evaluation Service Report for cleaning and installation instructions
- The ACI 318-08 version of the software does not account for adhesive anchor special design provisions corresponding to overhead applications.
- Checking the transfer of loads into the base material and the shear resistance are required in accordance with ACI 318 or the relevant standard!

## Fastening meets the design criteria!

## 7 Installation data

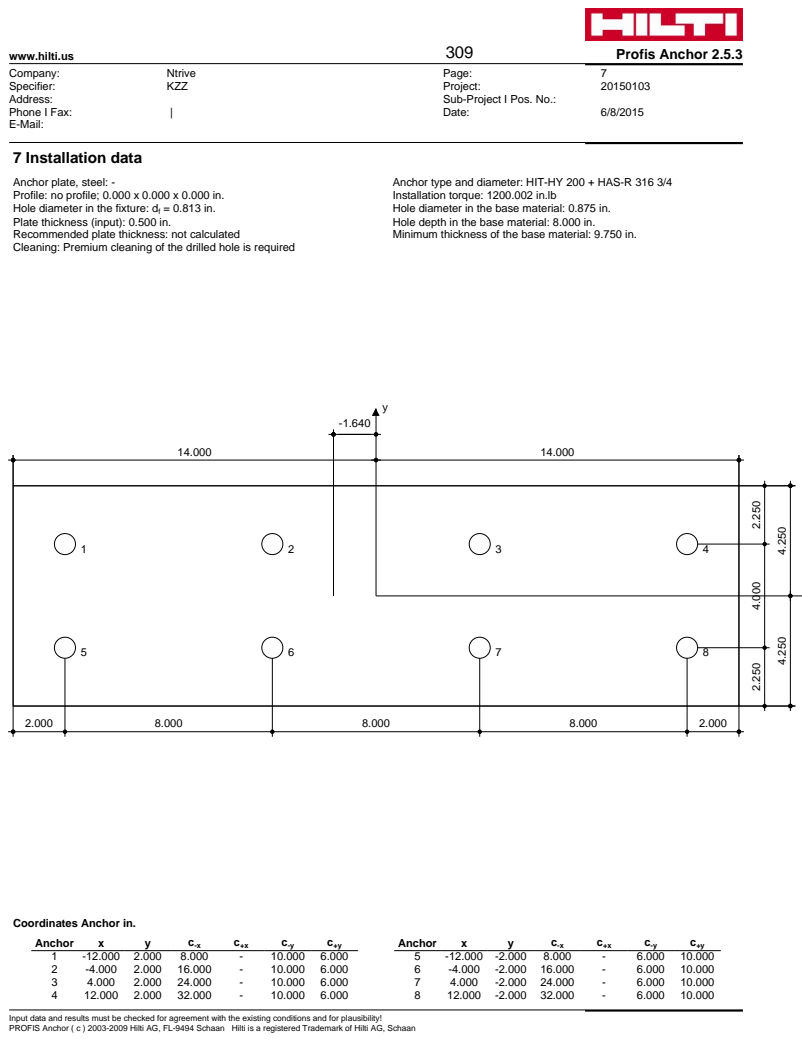
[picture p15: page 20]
Company: Specifier: Address: Phone I Fax: E-Mail:; Ntrive KZZ; Anchor; Anchor plate, steel: -; Anchor type and diameter: HIT-HY 200 + HAS-R 316 3/4; Profile: no profile; 0.000 x 0.000 x 0.000 in.; Installation torque: 1200.002 in.lb; Hole diameter in the base material: 0.875 in.; Plate thickness (input): 0.500 in.; Hole depth in the base material: 8.000 in.; Recommended plate thickness: not calculated; Minimum thickness of the base material: 9.750 in.

Page:
Project:
Sub-Project I Pos. No.:
Date:

Hole diameter in the fixture: df
Cleaning: Premium cleaning of the drilled hole is required

Coordinates Anchor in.

Company:
Specifier:
Address:
Phone I Fax:
E-Mail:

Ntrive
KZZ

Page:
Project:
Sub-Project I Pos. No.:
Date:

8
20150103

6/8/2015

## 8 Remarks; Your Cooperation Duties

- Any and all information and data contained in the Software concern solely the use of Hilti products and are based on the principles, formulas and security regulations in accordance with Hilti's technical directions and operating, mounting and assembly instructions, etc., that must be strictly complied with by the user. All figures contained therein are average figures, and therefore use-specific tests are to be conducted prior to using the relevant Hilti product. The results of the calculations carried out by means of the Software are based essentially on the data you put in. Therefore, you bear the sole responsibility for the absence of errors, the completeness and the relevance of the data to be put in by you. Moreover, you bear sole responsibility for having the results of the calculation checked and cleared by an expert, particularly with regard to compliance with applicable norms and permits, prior to using them for your specific facility. The Software serves only as an aid to interpret norms and permits without any guarantee as to the absence of errors, the correctness and the relevance of the results or suitability for a specific application.
- You must take all necessary and reasonable steps to prevent or limit damage caused by the Software. In particular, you must arrange for the regular backup of programs and data and, if applicable, carry out the updates of the Software offered by Hilti on a regular basis. If you do not use the AutoUpdate function of the Software, you must ensure that you are using the current and thus up-to-date version of the Software in each case by carrying out manual updates via the Hilti Website. Hilti will not be liable for consequences, such as the recovery of lost or damaged data or programs, arising from a culpable breach of duty by you.

# Ntrive Engineering

# 280 Shuman Blvd Ste 270

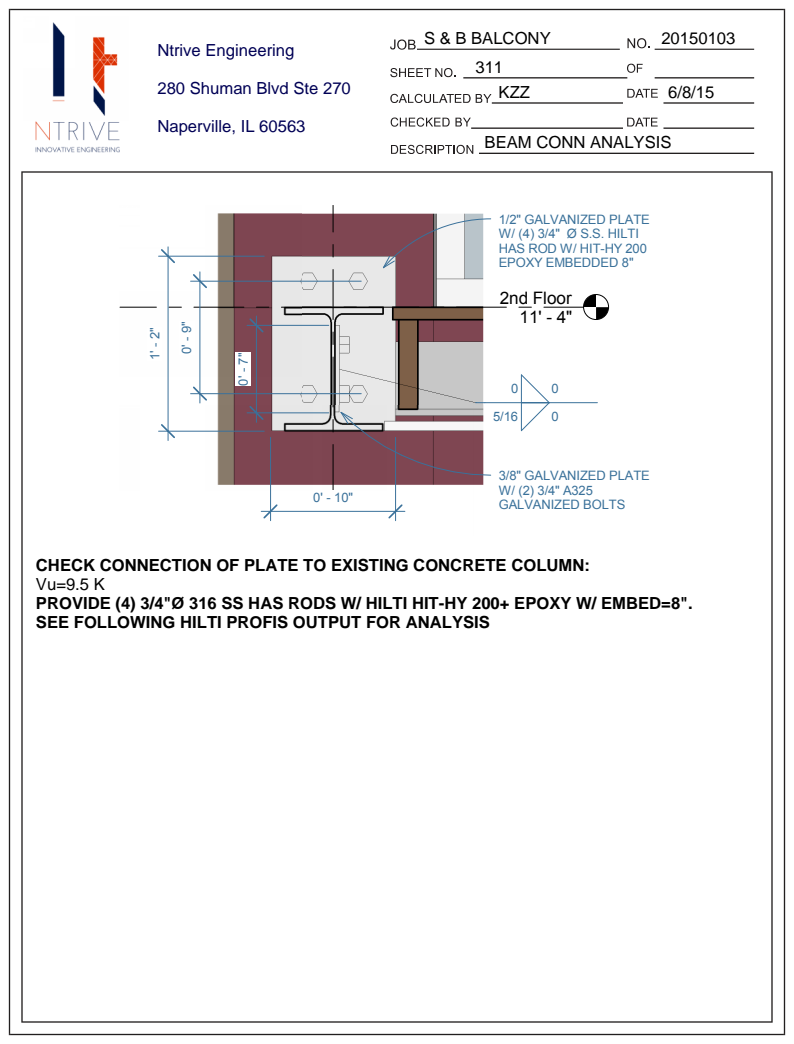
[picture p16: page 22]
Naperville, IL 60563; S & B BALCONY; 20150103 KZZ; 6/8/15 BEAM CONN ANALYSIS; 2nd Floor 11' - 4"; 3/8" GALVANIZED PLATE W/ (2) 3/4" A325 GALVANIZED BOLTS

1/2" GALVANIZED PLATE
W/ (4) 3/4" Ø S.S. HILTI
HAS ROD W/ HIT-HY 200
EPOXY EMBEDDED 8"

CHECK CONNECTION OF PLATE TO EXISTING CONCRETE COLUMN:
PROVIDE (4) 3/4"Ø 316 SS HAS RODS W/ HILTI HIT-HY 200+ EPOXY W/ EMBED=8".
SEE FOLLOWING HILTI PROFIS OUTPUT FOR ANALYSIS

Company:
Specifier:
Address:
Phone I Fax:
E-Mail:

Ntrive
KZZ

Page:
Project:
Sub-Project I Pos. No.:
Date:

1
20150103

6/8/2015

Specifier's comments:

## 1 Input data

Anchor type and diameter: | HIT-HY 200 + HAS-R 316 3/4
Effective embedment depth: | hef,act = 8.000 in. (hef,limit = - in.)
Material: | ASTM F 593
Evaluation Service Report: | ESR-3187
Issued I Valid: | 1/1/2015 | 3/1/2016
Proof: | Design method ACI 318-08 / Chem
Stand-off installation: | eb = 0.000 in. (no stand-off); t = 0.500 in.
Anchor plate: | lx x ly x t = 12.000 in. x 10.000 in. x 0.500 in.; (Recommended plate thickness: not calculated)
Profile: | Rectangular plates and bars (AISC); (L x W x T) = 6.750 in. x 0.750 in. x 0.000 in.
Base material: | cracked concrete, , fc ' = 3500 psi; h = 12.000 in., Temp. short/long: 32/32 °F
Installation: | hammer drilled hole, Installation condition: Dry
Reinforcement: | tension: condition B, shear: condition B; no supplemental splitting reinforcement present
| edge reinforcement: none or < No. 4 bar
Seismic loads (cat. C, D, E, or F) | no

Geometry [in.] & Loading [lb, in.lb]

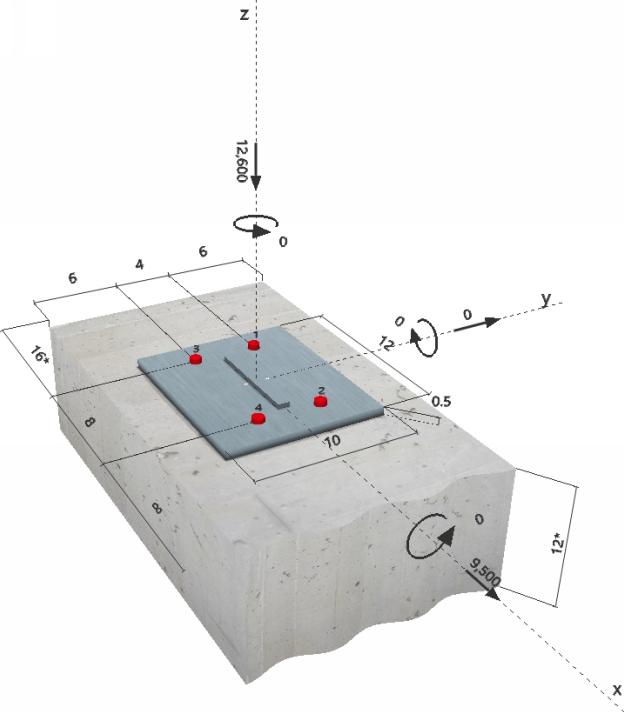
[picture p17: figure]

Company:
Specifier:
Address:
Phone I Fax:
E-Mail:

Ntrive
KZZ

Page:
Project:
Sub-Project I Pos. No.:
Date:

2
20150103

6/8/2015

## 2 Load case/Resulting anchor forces

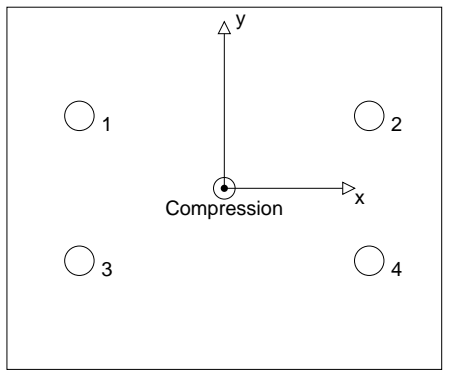
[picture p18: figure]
Compression

Load case: Design loads

Anchor reactions [lb]
Tension force: (+Tension, -Compression)
Anchor | Tension force | Shear force | Shear force x | Shear force y
1 | 0 | 2375 | 2375 | 0
2 | 0 | 2375 | 2375 | 0
3 | 0 | 2375 | 2375 | 0
4 | 0 | 2375 | 2375 | 0
max. concrete compressive strain: | 0.02 [‰]
max. concrete compressive stress: | 105 [psi]
resulting tension force in (x/y)=(0.000/0.000): | 0 [lb]
resulting compression force in (x/y)=(0.000/0.000): 12600 [lb]

## 3 Tension load

Load Nua [lb] | Capacity fNn [lb] | Utilization bN = Nua/fNn | Status
Steel Strength* | N/A | N/A | N/A | N/A
Bond Strength** | N/A | N/A | N/A | N/A
Sustained Tension Load Bond Strength* | N/A | N/A | N/A | N/A
Concrete Breakout Strength** | N/A | N/A | N/A | N/A
* anchor having the highest loading **anchor group (anchors in tension)

Company:
Specifier:
Address:
Phone I Fax:
E-Mail:

Ntrive
KZZ

Page:
Project:
Sub-Project I Pos. No.:
Date:

3
20150103

6/8/2015

## 4 Shear load

| Load Vua [lb] | Capacity fVn [lb] | Utilization bV = Vua/fVn | Status
Steel Strength* | 2375 | 10236 | 24 | OK
Steel failure (with lever arm)* | N/A | N/A | N/A | N/A
Pryout Strength (Concrete Breakout Strength controls)** | 9500 | 24072 | 40 | OK
Concrete edge failure in direction y-** | 9500 | 16156 | 59 | OK
* anchor having the highest loading **anchor group (relevant anchors)

### 4.1 Steel Strength

Vsa | = (n 0.6 Ase,V futa) | refer to ICC-ES ESR-3187
f Vsteel | Vua | ACI 318-08 Eq. (D-2)

Variables
n | Ase,V [in.²
] | futa [psi] | (n 0.6 Ase,V futa) [lb]
1 | 0.33 | 85000 | 17060
Calculations
Vsa [lb]
17060
Results
Vsa [lb] | fsteel | f Vsa [lb] | Vua [lb]
17060 | 0.600 | 10236 | 2375

### 4.2 Pryout Strength (Concrete Breakout Strength controls)

Vcpg = kcp [(
ANc

ANc0) yec,N yed,N yc,N ycp,N Nb]
ACI 318-08 Eq. (D-31)
f Vcpg | Vua | ACI 318-08 Eq. (D-2)
ANc | see ACI 318-08, Part D.5.2.1, Fig. RD.5.2.1(b)
ANc0 | = 9 h²
ef | ACI 318-08 Eq. (D-6)
yec,N = (
1
| 1 + 2 e'
N
3 hef

)
1.0 | ACI 318-08 Eq. (D-9)

yed,N = 0.7 + 0.3 (
ca,min
| 1.5hef) 1.0 | | ACI 318-08 Eq. (D-11)

ycp,N = MAX(
ca,min
cac

,

1.5hef
cac
| ) 1.0 | | ACI 318-08 Eq. (D-13)
Nb | = kc l f

'
c

h¹.5
ef | ACI 318-08 Eq. (D-7)

Variables
kcp | hef [in.] | ec1,N [in.] | ec2,N [in.] | ca,min [in.]
2 | 8.000 | 0.000 | 0.000 | 6.000
yc,N | cac [in.] | kc | l | f ' c [psi]
1.000 | 19.129 | 17 | 1 | 3500

Calculations
ANc [in.²
] | ANc0 [in.²
] | yec1,N | yec2,N | yed,N | ycp,N | Nb
| | | | | | [lb]
512.00 | 576.00 | 1.000 | 1.000 | 0.850 | 1.000 | 22757
Results
Vcpg [lb] | fconcrete | f Vcpg [lb] | Vua [lb]
34389 | 0.700 | 24072 | 9500

Company:
Specifier:
Address:
Phone I Fax:
E-Mail:

Ntrive
KZZ

Page:
Project:
Sub-Project I Pos. No.:
Date:

4
20150103

6/8/2015

### 4.3 Concrete edge failure in direction y-

Vcbg = (
AVc

AVc0) yec,V yed,V yc,V yh,V yparallel,V Vb
ACI 318-08 Eq. (D-22)
f Vcbg | Vua | ACI 318-08 Eq. (D-2)
AVc | see ACI 318-08, Part D.6.2.1, Fig. RD.6.2.1(b)
AVc0 | = 4.5 c²
a1 | ACI 318-08 Eq. (D-23)
yec,V = (
1
| 1 + 2e'
v
3ca1

)
1.0 | ACI 318-08 Eq. (D-26)

yed,V = 0.7 + 0.3(
ca2
1.5ca1) 1.0 | ACI 318-08 Eq. (D-28)
yh,V | =

1.5ca1
ha
1.0 | ACI 318-08 Eq. (D-29)
Vb | = (7 (
le
da

)

0.2

da) l f
'
c

c¹.5
| a1 | | ACI 318-08 Eq. (D-24)

Variables
ca1 [in.] | ca2 [in.] | ecV [in.] | yc,V | ha [in.]
6.000 | 16.000 | 0.000 | 1.000 | 12.000

le

[in.] | l | da
| | [in.] | f '
| | | c
| | | [psi] | yparallel,V
6.000 | 1.000 | 0.750 | 3500 | 2.000

Calculations
AVc [in.²
] | AVc0 [in.²
] | yec,V | yed,V | yh,V | Vb
| | | | | [lb]
234.00 | 162.00 | 1.000 | 1.000 | 1.000 | 7989
Results
Vcbg [lb] | fconcrete | f Vcbg [lb] | Vua [lb]
23080 | 0.700 | 16156 | 9500

## 5 Warnings

- Load re-distributions on the anchors due to elastic deformations of the anchor plate are not considered. The anchor plate is assumed to be sufficiently stiff, in order not to be deformed when subjected to the loading!

Input data and results must be checked for agreement with the existing conditions and for plausibility!
- Condition A applies when supplementary reinforcement is used. The factor is increased for non-steel Design Strengths except Pullout Strength and Pryout strength. Condition B applies when supplementary reinforcement is not used and for Pullout Strength and Pryout Strength. Refer to your local standard.
- Design Strengths of adhesive anchor systems are influenced by the cleaning method. Refer to the INSTRUCTIONS FOR USE given in the Evaluation Service Report for cleaning and installation instructions
- The ACI 318-08 version of the software does not account for adhesive anchor special design provisions corresponding to overhead applications.
- Checking the transfer of loads into the base material and the shear resistance are required in accordance with ACI 318 or the relevant standard!

## Fastening meets the design criteria!

## 6 Installation data

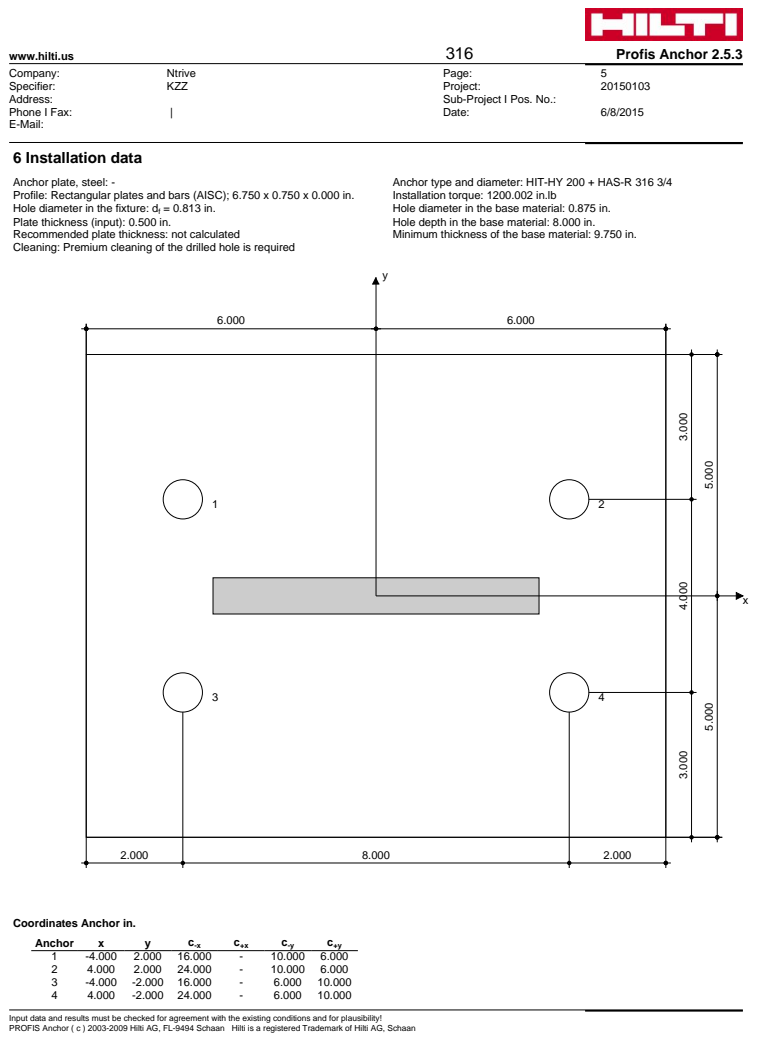
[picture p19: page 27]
Company: Specifier: Address: Phone I Fax: E-Mail:; Ntrive KZZ; Anchor; Anchor plate, steel: -; Anchor type and diameter: HIT-HY 200 + HAS-R 316 3/4; Profile: Rectangular plates and bars (AISC); 6.750 x 0.750 x 0.000 in.; Installation torque: 1200.002 in.lb; Hole diameter in the base material: 0.875 in.; Plate thickness (input): 0.500 in.; Hole depth in the base material: 8.000 in.; Recommended plate thickness: not calculated; Minimum thickness of the base material: 9.750 in.

Page:
Project:
Sub-Project I Pos. No.:
Date:

Hole diameter in the fixture: df
Cleaning: Premium cleaning of the drilled hole is required

Coordinates Anchor in.

Company:
Specifier:
Address:
Phone I Fax:
E-Mail:

Ntrive
KZZ

Page:
Project:
Sub-Project I Pos. No.:
Date:

6
20150103

6/8/2015

## 7 Remarks; Your Cooperation Duties

- Any and all information and data contained in the Software concern solely the use of Hilti products and are based on the principles, formulas and security regulations in accordance with Hilti's technical directions and operating, mounting and assembly instructions, etc., that must be strictly complied with by the user. All figures contained therein are average figures, and therefore use-specific tests are to be conducted prior to using the relevant Hilti product. The results of the calculations carried out by means of the Software are based essentially on the data you put in. Therefore, you bear the sole responsibility for the absence of errors, the completeness and the relevance of the data to be put in by you. Moreover, you bear sole responsibility for having the results of the calculation checked and cleared by an expert, particularly with regard to compliance with applicable norms and permits, prior to using them for your specific facility. The Software serves only as an aid to interpret norms and permits without any guarantee as to the absence of errors, the correctness and the relevance of the results or suitability for a specific application.
- You must take all necessary and reasonable steps to prevent or limit damage caused by the Software. In particular, you must arrange for the regular backup of programs and data and, if applicable, carry out the updates of the Software offered by Hilti on a regular basis. If you do not use the AutoUpdate function of the Software, you must ensure that you are using the current and thus up-to-date version of the Software in each case by carrying out manual updates via the Hilti Website. Hilti will not be liable for consequences, such as the recovery of lost or damaged data or programs, arising from a culpable breach of duty by you.

# Ntrive Engineering

# 280 Shuman Blvd Ste 270

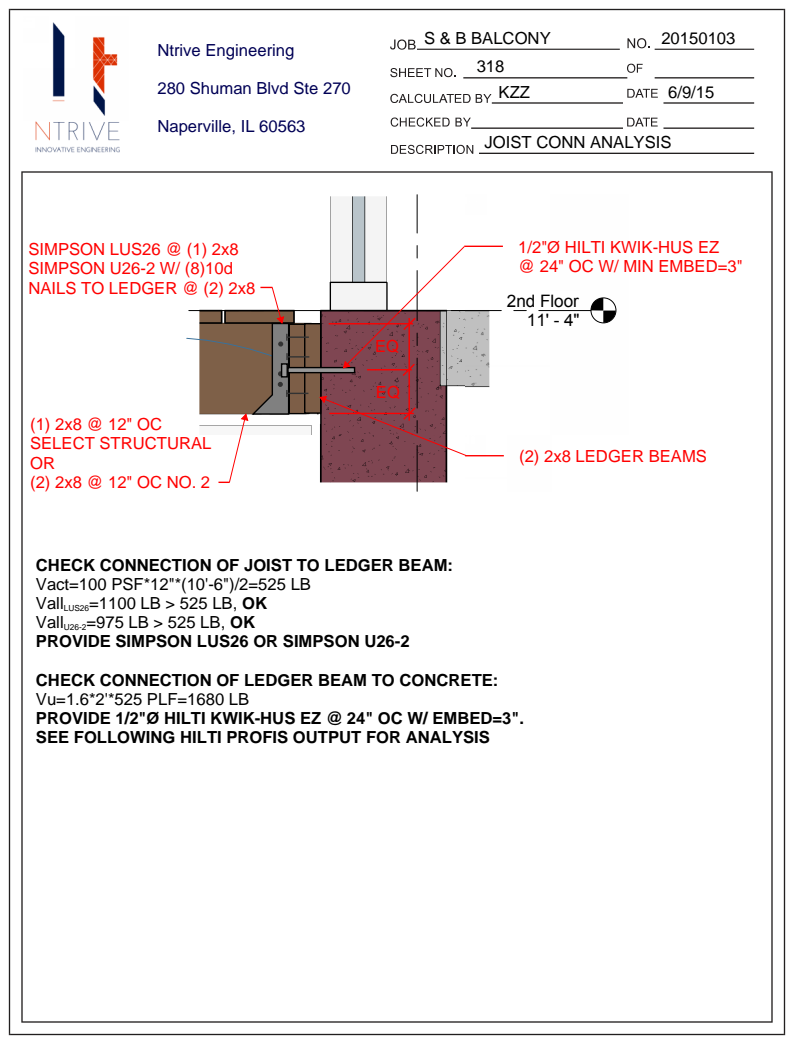
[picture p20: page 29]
Naperville, IL 60563; S & B BALCONY; 20150103 KZZ; 6/9/15 JOIST CONN ANALYSIS; 2nd Floor 11' - 4"; (2) 2x8 LEDGER BEAMS; (1) 2x8 @ 12" OC SELECT STRUCTURAL OR; EQEQ

SIMPSON LUS26 @ (1) 2x8
SIMPSON U26-2 W/ (8)10d
NAILS TO LEDGER @ (2) 2x8

1/2"Ø HILTI KWIK-HUS EZ
@ 24" OC W/ MIN EMBED=3"

CHECK CONNECTION OF JOIST TO LEDGER BEAM:
Vact=100 PSF*12"*(10'-6")/2=525 LB
VallLUS26=1100 LB > 525 LB, OK
VallU26-2=975 LB > 525 LB, OK
PROVIDE SIMPSON LUS26 OR SIMPSON U26-2
CHECK CONNECTION OF LEDGER BEAM TO CONCRETE:
Vu=1.6*2'*525 PLF=1680 LB
PROVIDE 1/2"Ø HILTI KWIK-HUS EZ @ 24" OC W/ EMBED=3".
SEE FOLLOWING HILTI PROFIS OUTPUT FOR ANALYSIS

Company:
Specifier:
Address:
Phone I Fax:
E-Mail:

Ntrive
KZZ

Page:
Project:
Sub-Project I Pos. No.:
Date:

1
20150103

6/9/2015

Specifier's comments:

## 1 Input data

Anchor type and diameter: | KWIK HUS-EZ (KH-EZ) 1/2 (3)
Effective embedment depth: | hef = 2.160 in., hnom = 3.000 in.
Material: | Carbon Steel
Evaluation Service Report: | ESR-3027
Issued I Valid: | 6/1/2014 | 12/1/2015
Proof: | Design method ACI 318 / AC193
Stand-off installation: | - (Recommended plate thickness: not calculated)
Profile: | no profile
Base material: | cracked concrete, 2500, fc ' = 2500 psi; h = 12.000 in.
Reinforcement: | tension: condition B, shear: condition B; no supplemental splitting reinforcement present
| edge reinforcement: none or < No. 4 bar
Seismic loads (cat. C, D, E, or F) | no

Geometry [in.] & Loading [lb, in.lb]

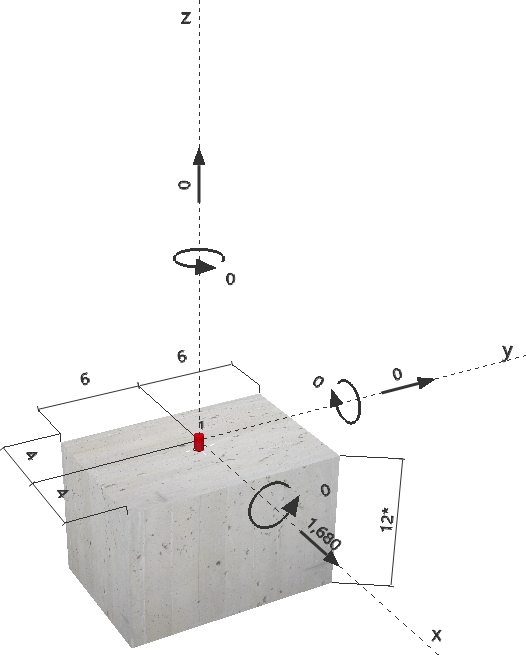
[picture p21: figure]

Company:
Specifier:
Address:
Phone I Fax:
E-Mail:

Ntrive
KZZ

Page:
Project:
Sub-Project I Pos. No.:
Date:

2
20150103

6/9/2015

## 2 Load case/Resulting anchor forces

Load case: Design loads

Anchor reactions [lb]
Tension force: (+Tension, -Compression)
Anchor | Tension force | Shear force | Shear force x | Shear force y
1 | 0 | 1680 | 1680 | 0
max. concrete compressive strain: | - [‰]
max. concrete compressive stress: | - [psi]
resulting tension force in (x/y)=(0.000/0.000): | 0 [lb]
resulting compression force in (x/y)=(0.000/0.000): 0 [lb]

## 3 Tension load

| Load Nua [lb] | Capacity fNn [lb] | Utilization bN = Nua/fNn | Status
Steel Strength* | N/A | N/A | N/A | N/A
Pullout Strength* | N/A | N/A | N/A | N/A
Concrete Breakout Strength** | N/A | N/A | N/A | N/A
* anchor having the highest loading **anchor group (anchors in tension)

Company:
Specifier:
Address:
Phone I Fax:
E-Mail:

Ntrive
KZZ

Page:
Project:
Sub-Project I Pos. No.:
Date:

3
20150103

6/9/2015

## 4 Shear load

| Load Vua [lb] | Capacity fVn [lb] | Utilization bV = Vua/fVn | Status
Steel Strength* | 1680 | 5547 | 31 | OK
Steel failure (with lever arm)* | N/A | N/A | N/A | N/A
Pryout Strength** | 1680 | 1889 | 89 | OK
Concrete edge failure in direction x+** | 1680 | 1857 | 91 | OK
* anchor having the highest loading **anchor group (relevant anchors)

### 4.1 Steel Strength

Vsa | = ESR value | refer to ICC-ES ESR-3027
f Vsteel | Vua | ACI 318-08 Eq. (D-2)

Variables
n | Ase,V [in.²
] | futa [psi]
1 | 0.16 | 112540
Calculations
Vsa [lb]
9245
Results
Vsa [lb] | fsteel | f Vsa [lb] | Vua [lb]
9245 | 0.600 | 5547 | 1680

### 4.2 Pryout Strength

Vcp = kcp [(
ANc

ANc0) yed,N yc,N ycp,N Nb]
ACI 318-08 Eq. (D-30)
f Vcp | Vua | ACI 318-08 Eq. (D-2)
ANc | see ACI 318-08, Part D.5.2.1, Fig. RD.5.2.1(b)
ANc0 = 9 h²
ef | ACI 318-08 Eq. (D-6)
yec,N = (
1
| 1 + 2 e'
N
3 hef

)
1.0 | ACI 318-08 Eq. (D-9)

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

ycp,N = MAX(
ca,min
cac

,

1.5hef
cac
| ) 1.0 | | ACI 318-08 Eq. (D-13)
Nb | = kc l f

'
c

h¹.5
ef | ACI 318-08 Eq. (D-7)

Variables
kcp | hef [in.] | ec1,N [in.] | ec2,N [in.] | ca,min [in.]
1 | 2.160 | 0.000 | 0.000 | 4.000
yc,N | cac [in.] | kc | l | f ' c [psi]
1.000 | 3.750 | 17 | 1 | 2500

Calculations
ANc [in.²
] | ANc0 [in.²
] | yec1,N | yec2,N | yed,N | ycp,N | Nb
| | | | | | [lb]
41.99 | 41.99 | 1.000 | 1.000 | 1.000 | 1.000 | 2698
Results
Vcp [lb] | fconcrete | f Vcp [lb] | Vua [lb]
2698 | 0.700 | 1889 | 1680

Company:
Specifier:
Address:
Phone I Fax:
E-Mail:

Ntrive
KZZ

Page:
Project:
Sub-Project I Pos. No.:
Date:

4
20150103

6/9/2015

### 4.3 Concrete edge failure in direction x+

Vcb = (
AVc

AVc0) yed,V yc,V yh,V yparallel,V Vb
ACI 318-08 Eq. (D-21)
f Vcb | Vua | ACI 318-08 Eq. (D-2)
AVc | see ACI 318-08, Part D.6.2.1, Fig. RD.6.2.1(b)
AVc0 = 4.5 c²
a1 | ACI 318-08 Eq. (D-23)
yec,V = (
1
| 1 + 2e'
v
3ca1

)
1.0 | ACI 318-08 Eq. (D-26)

yed,V = 0.7 + 0.3(
ca2
1.5ca1) 1.0 | ACI 318-08 Eq. (D-28)

yh,V =

1.5ca1
ha
1.0 | ACI 318-08 Eq. (D-29)
Vb | = (7 (
le
da

)

0.2

da) l f
'
c

c¹.5
| a1 | | ACI 318-08 Eq. (D-24)

Variables
ca1 [in.] | ca2 [in.] | ecV [in.] | yc,V | ha [in.]
4.000 | 6.000 | 0.000 | 1.000 | 12.000

le

[in.] | l | da
| | [in.] | f '
| | | c
| | | [psi] | yparallel,V
2.160 | 1.000 | 0.500 | 2500 | 1.000

Calculations
AVc [in.²
] | AVc0 [in.²
] | yec,V | yed,V | yh,V | Vb
| | | | | [lb]
72.00 | 72.00 | 1.000 | 1.000 | 1.000 | 2653
Results
Vcb [lb] | fconcrete | f Vcb [lb] | Vua [lb]
2653 | 0.700 | 1857 | 1680

## 5 Warnings

- Load re-distributions on the anchors due to elastic deformations of the anchor plate are not considered. The anchor plate is assumed to be sufficiently stiff, in order not to be deformed when subjected to the loading!

Input data and results must be checked for agreement with the existing conditions and for plausibility!
- Condition A applies when supplementary reinforcement is used. The factor is increased for non-steel Design Strengths except Pullout Strength and Pryout strength. Condition B applies when supplementary reinforcement is not used and for Pullout Strength and Pryout Strength. Refer to your local standard.
- Refer to the manufacturer's product literature for cleaning and installation instructions.
- Checking the transfer of loads into the base material and the shear resistance are required in accordance with ACI 318 or the relevant standard!

## Fastening meets the design criteria!

Company:
Specifier:
Address:
Phone I Fax:
E-Mail:

Ntrive
KZZ

Page:
Project:
Sub-Project I Pos. No.:
Date:

5
20150103

6/9/2015

## 6 Installation data

Anchor plate, steel: - | Anchor type and diameter: KWIK HUS-EZ (KH-EZ) 1/2 (3)
Profile: - | Installation torque: 540.001 in.lb
Hole diameter in the fixture: - | Hole diameter in the base material: 0.500 in.
Plate thickness (input): - | Hole depth in the base material: 3.375 in.
Recommended plate thickness: - | Minimum thickness of the base material: 4.750 in.
Cleaning: Manual cleaning of the drilled hole according to instructions for use is required.

Coordinates Anchor in.
Anchor | x | y | c-x | c+x | c-y | c+y
1 | 0.000 | 0.000 | 4.000 | 4.000 | 6.000 | 6.000

## 7 Remarks; Your Cooperation Duties

- Any and all information and data contained in the Software concern solely the use of Hilti products and are based on the principles, formulas and security regulations in accordance with Hilti's technical directions and operating, mounting and assembly instructions, etc., that must be strictly complied with by the user. All figures contained therein are average figures, and therefore use-specific tests are to be conducted prior to using the relevant Hilti product. The results of the calculations carried out by means of the Software are based essentially on the data you put in. Therefore, you bear the sole responsibility for the absence of errors, the completeness and the relevance of the data to be put in by you. Moreover, you bear sole responsibility for having the results of the calculation checked and cleared by an expert, particularly with regard to compliance with applicable norms and permits, prior to using them for your specific facility. The Software serves only as an aid to interpret norms and permits without any guarantee as to the absence of errors, the correctness and the relevance of the results or suitability for a specific application.
- You must take all necessary and reasonable steps to prevent or limit damage caused by the Software. In particular, you must arrange for the regular backup of programs and data and, if applicable, carry out the updates of the Software offered by Hilti on a regular basis. If you do not use the AutoUpdate function of the Software, you must ensure that you are using the current and thus up-to-date version of the Software in each case by carrying out manual updates via the Hilti Website. Hilti will not be liable for consequences, such as the recovery of lost or damaged data or programs, arising from a culpable breach of duty by you.

# Ntrive Engineering

# 280 Shuman Blvd Ste 270

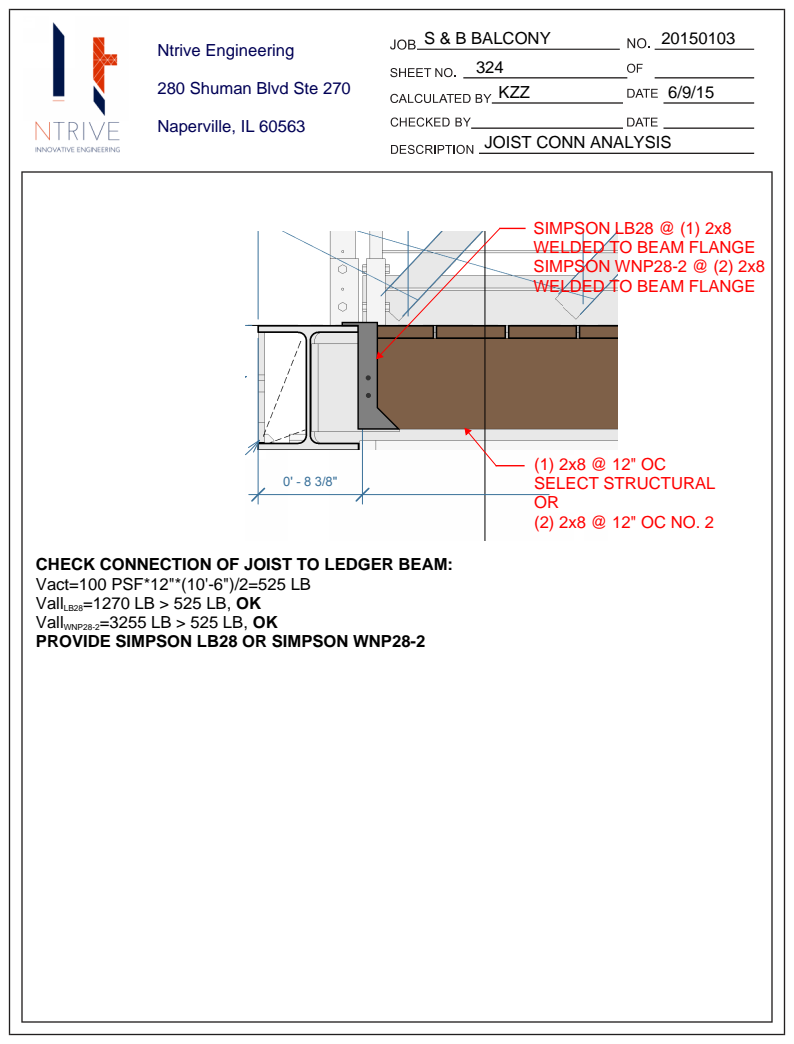
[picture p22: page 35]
Naperville, IL 60563; S & B BALCONY; 20150103 KZZ; 6/9/15 JOIST CONN ANALYSIS; (1) 2x8 @ 12" OC SELECT STRUCTURAL OR

SIMPSON LB28 @ (1) 2x8
WELDED TO BEAM FLANGE
SIMPSON WNP28-2 @ (2) 2x8

CHECK CONNECTION OF JOIST TO LEDGER BEAM:
Vact=100 PSF*12"*(10'-6")/2=525 LB
VallLB28=1270 LB > 525 LB, OK
VallWNP28-2=3255 LB > 525 LB, OK
PROVIDE SIMPSON LB28 OR SIMPSON WNP28-2

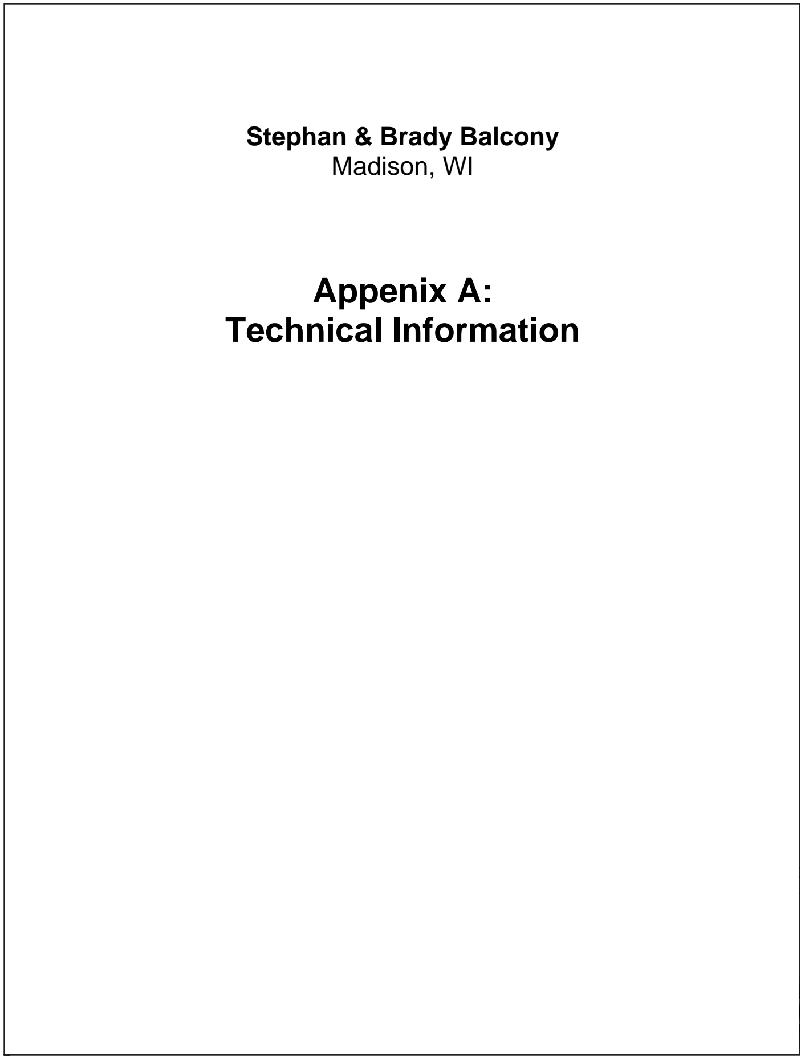
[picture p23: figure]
Stephan & Brady Balcony Madison, WI; Appenix A: Technical Information

C-C-2015 © 2015 SIMPSON STRONG-TIE COMPANY INC. PRINTED 12/14

# 76 Solid Sawn Joist Hangers

See Hanger tables on pages 77-82. See Hanger Options on pages 233-243 for hanger modifications, which may result in reduced loads.
All hangers in this series have double shear nailing. This innovation distributes the load through two points on each joist nail for greater strength. It also allows the use of fewer nails, faster installation, and the use of standard nails for all connections. (Do not bend or
remove tabs.)
MATERIAL: See tables, pages 77-82.
FINISH: Galvanized. Some products available in stainless steel or ZMAX® coating; see Corrosion Information, pages 13-15. INSTALLATION • Use all specified fasteners. See General Notes.
- Nails must be driven at an angle through the joist or truss into the header to achieve the table loads.
- Not designed for welded or nailer applications.
- 16d sinkers (0.148" dia. x 3¹

⁄4" long) may be used where 10d commons are specified with no reduction in load. Where 16d commons are specified, 10d commons or 16d sinkers (0.148" dia. x 3¹

⁄4" long) may be used at 0.85 of the table load.
- With 3x carrying members, use 16dx2¹

⁄2" nails into
the header and 16d commons into the joist with no load reduction.
- With 2x carrying members, use 10dx1¹

⁄2" nails into the
header and 10d commons into the joist, reduce the load to 0.64 of the table value.
- Use stainless-steel (SS) nails with stainless-steel
(SS) hangers.
OPTIONS: • LUS hangers cannot be modified.
- HUS hangers available with the header flanges turned in for 2-2x (3¹

⁄8") and 4x only, with no load reduction. See the HUSC Concealed Flange illustration.

Typical LUS28 Installation use 0.148x3" (10d common)
or 0.148x3¹

⁄4" (16d sinker) nail

Double-Shear
Nailing
Top View

Dome Double-Shear
Nailing Side View
(available on
some models)
U.S. Patent 5,603,580

Double-Shear
Nailing
Side View
Do not
bend tab

### LUS/HUS/HHUS/HGUS Double Shear Joist Hangers

Solid Sawn Joist Hangers

# FACE MOUNT HANGERS – SOLID SAWN LUMBER (DF/SP)

This product is preferable to similar connectors because of
a) easier installation, b) higher loads, c) lower installed cost, or a combination of these features.

H

W

B

1" for 2x’s 11
⁄16" for 3x’s and 4x’s

### LUS28

### HUS210

(HUS26, HUS28,
and HHUS similar) | HUS412

### HUSC

Concealed Flanges
(not available for HHUS,
HGUS and HUS2x)

CODES: See page xx for Code Reference Key Chart.

These products are available with additional corrosion protection. Additional products on this page may also be available with this option, check with Simpson Strong-Tie for details.

See footnotes on page 79.

These products are approved for installation with the Strong-Drive ® SD Connector screw. See page 27 for more information.

25⁄8"

### HGUS3.25/12

### HGUS46

Joist Size | Model No. | Ga | Dimensions (in.) | Min/ Max | Fasteners | DF/SP Allowable Loads | Installed Cost Index (ICI) | Code
W | H | B | | Header | Joist | (160) | Floor (100) | Snow (115) | Roof (125) | Ref. Uplift

SAWN LUMBER SIZES
2X4 | | LU24 | 20 18 | 1⁹ 1⁹ ⁄16 | 3¹ ⁄8 | 1¹ ⁄2 | — | 4-16d | 2-10dx1¹ ⁄2 | 265 | 555 | 635 | 685 | Lowest | I7, I27, F6, L5, L17 LUS24
| | | | ⁄16 | 3¹ ⁄8 | 1³ ⁄4 | — | 4-10d | 2-10d | 490 | 670 | 765 | 825 | +3%
| | U24 | 14 16 | 1⁹ 1⁹ ⁄16 | 3¹ ⁄8 | 1¹ ⁄2 | — | 4-16d | 2-10dx1¹ ⁄2 | 265 | 575 | 655 | 705 | +67% | I7, F6, L17 HU26
| | | | ⁄16 | 3¹ ⁄16 | 2¹ ⁄4 | — | 4-16d | 2-10dx1¹ ⁄2 | 335 | 595 | 670 | 720 | +295%
DBL 2X4 | LUS24-2 | | 18 | 3¹ ⁄8 | 3¹ ⁄8 | 2 | — | 4-16d | 2-16d | 440 | 800 | 910 | 985 | Lowest | I7, I27, F6, L5, L17
| U24-2 | | 16 14 | 3¹ 3¹ ⁄8 | 3 | 2 | — | 4-16d | 2-10d | 370 | 575 | 655 | 705 | +33% | I7, F6, L17 HU24-2/HUC24-2
| | | | ⁄8 | 3¹ ⁄16 | 2¹ ⁄2 | — | 4-16d | 2-10d | 380 | 380 | 595 | 720 | +240%
2x6 | | LUS26 | 18 20 | 1⁹ 1⁹ ⁄16 | 4³ ⁄4 | 1³ ⁄4 | — | 4-10d | 4-10d | 1165 | 865 | 990 | 1070 | Lowest | I7, I27, F6, L5, L17 LU26
| | | | ⁄16 | 4³ ⁄4 | 1¹ ⁄2 | — | 6-16d | 4-10dx1¹ ⁄2 | 565 | 835 | 950 | 1030 | +6%
| | U26 | 16 | 1⁹ ⁄16 | 4³ ⁄4 | 2 | — | 6-16d | 4-10dx1¹ ⁄2 | 585 | 865 | 980 | 1055 | +43%
| | LUC26Z | 18 | 1 ⁄16 | 4³ ⁄4 | 1³ ⁄4 | — | 6-16d | 4-10dx1¹ ⁄2 | 730 | 845 | 965 | 1040 | +160% | I7, F6, L17 ⁹
| | HU26 | 14 | 1⁹ ⁄16 | 3¹ ⁄16 | 2¹ ⁄4 | — | 4-16d | 2-10dx1¹ ⁄2 | 335 | 335 | 595 | 720 | +179%
| | HUS26 | 16 | 1⁵ ⁄8 | 5³ ⁄8 | 3 | — | 14-16d | 6-16d | 1550 | 2720 | 3095 | 3335 | +276% | I7, I27, F6, L5, L17
DBL 2X6 | LUS26-2 | | 18 | 3¹ ⁄8 | 4⁷ ⁄8 | 2 | — | 4-16d | 4-16d | 1165 | 1030 | 1180 | 1280 | Lowest
| U26-2 | | 14 16 | 3¹ 3¹ ⁄8 | 5 | 2 | — | 8-16d | 4-10d | 740 | 1150 | 1305 | 1410 | +65% | I7, F6, L17 HUS26-2/HUSC26-2
| | | | ⁄8 | 5³ ⁄16 | 2 | — | 4-16d | 4-16d | 1235 | 1065 | 1210 | 1305 | +172%
| HU26-2/HUC26-2 | | 14 | 3¹ ⁄8 | 5³ ⁄8 | 2¹ ⁄2 | Min | 8-16d | 4-10d | 760 | 1190 | 1345 | 1445 | +233% | I7, I27, F6, L5, L17
| | | 14 | 3¹ ⁄8 | 5³ ⁄8 | 2¹ ⁄2 | Max | 12-16d | 6-10d | 1135 | 1785 | 2015 | 2165 | +254% | I7, F6, L17

# 77 Solid Sawn Joist Hangers

# FACE MOUNT HANGERS – SOLID SAWN LUMBER (DF/SP)

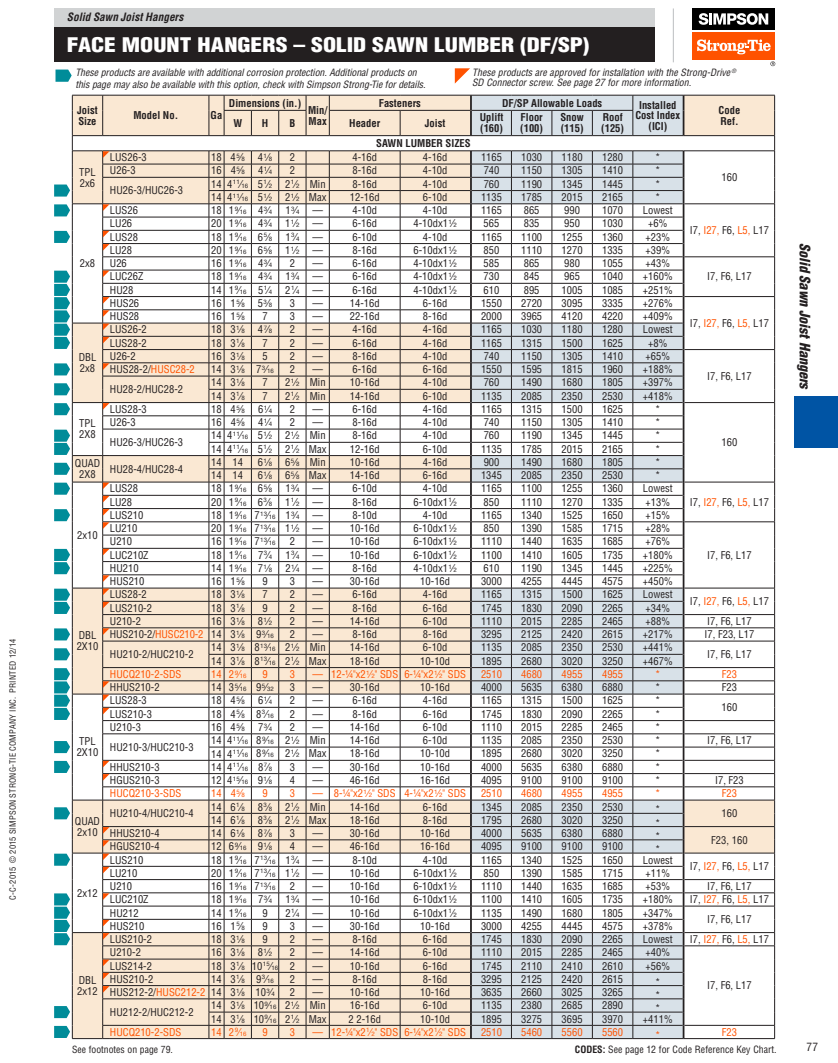
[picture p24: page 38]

Solid Sawn Joist Hangers

These products are available with additional corrosion protection. Additional products on
this page may also be available with this option, check with Simpson Strong-Tie for details.

These products are approved for installation with the Strong-Drive ®
SD Connector screw. See page 27 for more information.

Joist Size | Model No. | Ga | Dimensions (in.) | Min/ Max | Fasteners | DF/SP Allowable Loads | Installed Cost Index (ICI) | Code

W | H | B | | Header | Joist | (160) | Floor (100) | Snow (115) | Roof (125) | Ref. Uplift

SAWN LUMBER SIZES

TPL 2x6 | LUS26-3 | 18 | 4⁵ ⁄8 | 4¹ ⁄8 | 2 | | 4-16d | 4-16d | 1165 | 1030 | 1180 | 1280 | *
16 | 4⁵ ⁄8 | 4¹ ⁄4 | 2 | | 8-16d | 4-10d | 740 | 1150 | 1305 | 1410 | * | 160 U26-3
HU26-3/HUC26-3 | 14 | 4¹¹⁄16 | 5¹ ⁄2 | 2¹ ⁄2 | Min | 8-16d | 4-10d | 760 | 1190 | 1345 | 1445 | *

14 | 4¹¹⁄16 | 5¹ ⁄2 | 2¹ ⁄2 | Max | 12-16d | 6-10d | 1135 | 1785 | 2015 | 2165 | *

2x8 | LUS26 | 18 | 1⁹ ⁄16 | 4³ ⁄4 | 1³ ⁄4 | — | 4-10d | 4-10d | 1165 | 865 | 990 | 1070 | Lowest
20 | 1⁹ ⁄16 | 4³ ⁄4 | 1¹ ⁄2 | — | 6-16d | 4-10dx1¹ ⁄2 | 565 | 835 | 950 | 1030 | +6% | I7, I27, F6, L5, L17 LU26
LUS28 | 18 | 1⁹ ⁄16 | 6⁵ ⁄8 | 1³ ⁄4 | — | 6-10d | 4-10d | 1165 | 1100 | 1255 | 1360 | +23%
LU28 | 20 | 1⁹ ⁄16 | 6⁵ ⁄8 | 1¹ ⁄2 | — | 8-16d | 6-10dx1¹ ⁄2 | 850 | 1110 | 1270 | 1335 | +39%
U26 | 16 | 1⁹ ⁄16 | 4³ ⁄4 | 2 | — | 6-16d | 4-10dx1¹ ⁄2 | 585 | 865 | 980 | 1055 | +43%
LUC26Z | 18 | 1 ⁄16 | 4³ ⁄4 | 1³ ⁄4 | — | 6-16d | 4-10dx1¹ ⁄2 | 730 | 845 | 965 | 1040 | +160% | I7, F6, L17 ⁹
HU28 | 14 | 1⁹ ⁄16 | 5¹ ⁄4 | 2¹ ⁄4 | — | 6-16d | 4-10dx1¹ ⁄2 | 610 | 895 | 1005 | 1085 | +251%
HUS26 | 16 | 1⁵ ⁄8 | 5³ ⁄8 | 3 | — | 14-16d | 6-16d | 1550 | 2720 | 3095 | 3335 | +276%
16 | 1⁵ ⁄8 | 7 | 3 | — | 22-16d | 8-16d | 2000 | 3965 | 4120 | 4220 | +409% | I7, I27, F6, L5, L17 HUS28
DBL 2x8 | LUS26-2 | 18 | 3¹ ⁄8 | 4⁷ ⁄8 | 2 | — | 4-16d | 4-16d | 1165 | 1030 | 1180 | 1280 | Lowest
LUS28-2 | 18 | 3¹ ⁄8 | 7 | 2 | — | 6-16d | 4-16d | 1165 | 1315 | 1500 | 1625 | +8%
U26-2 | 16 | 3¹ ⁄8 | 5 | 2 | — | 8-16d | 4-10d | 740 | 1150 | 1305 | 1410 | +65%
14 | 3¹ ⁄8 | 7³ ⁄16 | 2 | — | 6-16d | 6-16d | 1550 | 1595 | 1815 | 1960 | +188% | I7, F6, L17 HUS28-2/HUSC28-2
HU28-2/HUC28-2 | 14 | 3¹ ⁄8 | 7 | 2¹ ⁄2 | Min | 10-16d | 4-10d | 760 | 1490 | 1680 | 1805 | +397%

14 | 3¹ ⁄8 | 7 | 2¹ ⁄2 | Min | 14-16d | 6-10d | 1135 | 2085 | 2350 | 2530 | +418%

TPL 2X8 | LUS28-3 | 18 | 4⁵ ⁄8 | 6¹ ⁄4 | 2 | — | 6-16d | 4-16d | 1165 | 1315 | 1500 | 1625 | * | 160
U26-3 | 16 | 4⁵ ⁄8 | 4¹ ⁄4 | 2 | — | 8-16d | 4-10d | 740 | 1150 | 1305 | 1410 | *

QUAD 2X8 | HU28-4/HUC28-4 | 14 | 14 | 6¹ ⁄8 | 6⁵ ⁄8 | Min | 10-16d | 4-16d | 900 | 1490 | 1680 | 1805 | *

14 | 14 | 6¹ ⁄8 | 6⁵ ⁄8 | Max | 14-16d | 6-16d | 1345 | 2085 | 2350 | 2530 | *

2x10 | LUS28 | 18 | 1⁹ ⁄16 | 6⁵ ⁄8 | 1³ ⁄4 | — | 6-10d | 4-10d | 1165 | 1100 | 1255 | 1360 | Lowest
LU28 | 20 | 1 ⁄16 | 6³ ⁄8 | 1¹ ⁄2 | — | 8-16d | 6-10dx1¹ ⁄2 | 850 | 1110 | 1270 | 1335 | +13% | I7, I27, F6, L5, L17 ⁹
LUS210 | 18 | 1⁹ ⁄16 | 7¹³⁄16 | 1³ ⁄4 | — | 8-10d | 4-10d | 1165 | 1340 | 1525 | 1650 | +15%
LU210 | 20 | 1⁹ ⁄16 | 7¹³⁄16 | 1¹ ⁄2 | — | 10-16d | 6-10dx1¹ ⁄2 | 850 | 1390 | 1585 | 1715 | +28% | I7, F6, L17
U210 | 16 | 1⁹ ⁄16 | 7¹³⁄16 | 2 | — | 10-16d | 6-10dx1¹ ⁄2 | 1110 | 1440 | 1635 | 1685 | +76%
LUC210Z | 18 | 1⁹ ⁄16 | 7³ ⁄4 | 1³ ⁄4 | — | 10-16d | 6-10dx1¹ ⁄2 | 1100 | 1410 | 1605 | 1735 | +180%
HU210 | 14 | 1⁹ ⁄16 | 7¹ ⁄8 | 2¹ ⁄4 | — | 8-16d | 4-10dx1¹ ⁄2 | 610 | 1190 | 1345 | 1445 | +225%
HUS210 | 16 | 1⁵ ⁄8 | 9 | 3 | — | 30-16d | 10-16d | 3000 | 4255 | 4445 | 4575 | +450%
DBL 2X10 | LUS28-2 | 18 18 | 3¹ 3¹ ⁄8 | 7 | 2 | — | 6-16d | 4-16d | 1165 | 1315 | 1500 | 1625 | Lowest | I7, I27, F6, L5, L17 LUS210-2

U210-2 | 16 | 3¹ ⁄8 | 8¹ ⁄2 | 2 | — | 14-16d | 6-10d | 1110 | 2015 | 2285 | 2465 | +88% | I7, F6, L17
HUS210-2/HUSC210-2 | 14 | 3¹ ⁄8 | 9³ ⁄16 | 2 | — | 8-16d | 8-16d | 3295 | 2125 | 2420 | 2615 | +217% | I7, F23, L17
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

C-C-2015 © 2015 SIMPSON STRONG-TIE COMPANY INC. PRINTED 12/14

# 84 Solid Sawn Joist Hangers

Nailer
attachment
per Designer 1¹⁄2" Min.

Typical BA Installation on Wood Nailer (LB, B similar)

Factory Weld

Typical BD
Saddle Installation

B
(HHB similar)

LB, BA, B and HHB are acceptable for weld-on applications. See Installation Information.

The new, next-generation LBAZ and JBA hangers provide higher loads for 2x10, 2x12 and 2x14 members in 14 gauge and 18 gauge steel, respectively. The new nail locations on the JBA enable effective use with nailers.
The B and BA hangers are cost effective hangers featuring min/max joist nailing option. Min Nailing featuring Positive Angle Nailing targets moderate load conditions whereas the Max Nailing generates capacities for higher loads. The unique two level embossment provides added stiffness to the top flange.
See tables on pages 87-91. See Hanger Options on pages 233-243
for hanger modifications, which may result in reduced loads. MATERIAL: See tables, pages 87-91.
FINISH: BA, JB, JBA, LB, LBAZ and B—Galvanized; HHB–all saddle hangers and all welded sloped and special hangers—Simpson Strong-Tie® gray paint. BA, LB, B and HHB may be ordered hot-dip galvanized, specify HDG.
INSTALLATION: • Use specified fasteners. See General Notes and nailer table notes.
- LBAZ, BA, B and HHB may also be welded to steel headers with weld size to match material thickness (approximate thickness shown). The minimum required weld to the top flanges is ¹

⁄8" x 2" (¹

⁄8" x 1⁷

⁄16"
for LBAZ) fillet weld to each side of each top flange tab for 14 and 12 gauge and ³

⁄16" x 2" fillet weld to each side of each top flange tab for 7 gauge. Distribute the weld equally on both top flanges. Welding cancels the top and face nailing requirements. Consult the code
for special considerations when welding galvanized steel. The area should be well-ventilated (see page 17 for welding information). Weld on applications produce the maximum allowable down load listed. For uplift loads refer to technical bulletin T-WELDUPLFT.
- Ledgers must be evaluated for each application separately. Check TF dimension, nail length and nail location on ledger.
- Refer to technical bulletin T-SLOPEJST for information regarding load reductions on selected hangers which can be used without modification to support joists which have shallow slopes (≤³

⁄4:12).
OPTIONS: B and HHB
- Other widths are available; specify W dimension
(the minimum W dimension is 1⁹

⁄16" for B and 3¹

⁄4" for HHB).
- See Hanger Options, pages 233-243. BA, JB, JBA, LB and LBAZ hangers cannot be modified. Use LBV as an alternative for the JBA/LBAZ.
CODES: See page 12 for Code Reference Key Chart.

# TOP FLANGE HANGERS JB/JBA/LB/LBAZ/BA/B/HHB Joist, Beam and Purlin Hangers

Solid Sawn Joist Hangers

## Nailer Table⁵

1. Uplift values are for DF/SP nailers only. Refer to technical bulletin T-NAILERUPLFT for SPF values.
2. For joist members 2¹

⁄2" or wider, 16dx2¹

⁄2" joist nails
should be installed for additional uplift loads on the 3x and 4x nailer applications of 970 lbs. and 1010 lbs. respectively.
3. If joist nailing is increased to (8)-10dx1¹

⁄2, higher
uplift loads are allowed. See technical bulletin T-NAILERUPLFT.
4. If joist nailing is increased to (6)-16dx2¹

⁄2, higher
uplift loads are allowed for joist members at least 2¹

⁄2" wide. See technical bulletin T-NAILERUPLFT.
5. Attachment of nailer to supporting member is by the Designer.

This product is preferable to similar connectors because of
a) easier installation, b) higher loads, c) lower installed cost, or a combination of these features.

BA
U.S. Patent 7,334,372

3"

### JBA

(LBAZ similar)

Model No. | Nailer | Top Flange Nailing | Joist Nailing | Allowable Loads
Uplift¹ (160) | DF/SP | SPF/HF
JB210A JB212A JB214A | 2x | 6-10dx1¹ ⁄2 | 2-10dx1¹ ⁄2 | 315 | 1265 | 965
| 3x | 6-16dx2¹ ⁄2 | 2-10dx1¹ ⁄2 | 315 | 1290 | —
LB26 | 2x | 4-10dx1¹ ⁄2 | 2-10dx1¹ ⁄2 | — | 850 | —
LB28 | 2x | 4-10dx1¹ ⁄2 | 2-10dx1¹ ⁄2 | — | 915 | —
LB210AZ LB212AZ LB214AZ | 2x | 6-10dx1¹ ⁄2 | 2-10dx1¹ ⁄2 | 375 | 1265 | 1065
| 3x | 6-16dx2¹ ⁄2 | 2-10dx1¹ ⁄2 | 375 | 1290 | —
LB216 | 2x | 4-10dx1¹ ⁄2 | 2-10dx1¹ ⁄2 | — | 1150 | —
BA | 2x | 10-10dx1¹ ⁄2 | 2-10dx1¹ ⁄2 | 265³ | 2220 | 1755
| 2-2x | 14-10d | 2-10dx1¹ ⁄2 | 265³ | 2695 | 2235
| 3x | 14-16dx2¹ ⁄2 | 2-10dx1¹ ⁄2 | 265³ | 3230 | —
| 4x | 14-16d | 2-10dx1¹ ⁄2 | 265³ | 3230 | —
B | 2-2x | 14-10d | 6-10dx1¹ ⁄2 | 710⁴ | 3615 | 2770
| 3x | 14-16dx2¹ ⁄2 | 6-10dx1¹ ⁄2 | 830⁴ | 3725 | —
| 4x | 14-16d | 6-10dx1¹ ⁄2 | 830⁴ | 3800 | —

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
C-C-2015 © 2015 SIMPSON STRONG-TIE COMPANY INC. PRINTED 12/14

# 86 Solid Sawn Joist Hangers

# TOP FLANGE HANGERS W/WPU/WNP/WM/WMU/HW/HWU/GLT/HGLT

Solid Sawn Joist Hangers

12 Ga.
Top Flange

Fasteners
not required
in this hole

7" - 8"

33⁄4"

23⁄4"

WM
(WMU
similar)

2¹⁄4"

2¹⁄2"
61⁄2"

12 Ga.
Top
Flange

W

3 Ga.
Top Flange

HW
(HWU
similar)

25⁄16"

25⁄16"
7 Ga.
Top Flange

8"

### WPU

1. Code values are based on DF/SP header species.
2. WMU, WPU and HWU uplift loads have been increased for wind or earthquake loading with no further increase allowed. Reduce where other loads govern.
3. For hanger heights exceeding the joist height, the allowable load is 0.50 of the table load.
4. Mid-wall Installation requires minimum of one grouted course above and below the hanger.
5. NAILS: 16d = 0.162" dia. x 3¹

⁄2"
long, 10d = 0.148" dia. x 3" long, 10dx1¹

⁄2 = 0.148" dia. x 1¹

⁄2" long.
See pages 22-23 for other nail sizes and information.

Typical WM
Mid-Wall Installation
See pages 173-174 for
models and information.

W SERIES WITH VARIOUS HEADER APPLICATIONS

7 Ga.
Top
Flange

### WP/WNP

Installation on Wood Nailer

12"

### HGLT

(fasteners included)
See pages 104-105 for GLT and HGLT information.

10" for GLT4
12" for GLT6

### GLT

(fasteners included)

The W, WPU, HWU and HW series purlin hangers offer the greatest design flexibility and versatility. WMs are designed for use on standard 8" grouted masonry block wall construction.
MATERIAL: See tables on pages 87-91.
FINISH: Simpson Strong-Tie® gray paint; hot-dip galvanized available:
specify HDG, contact Simpson Strong-Tie.
INSTALLATION: • Use all specified fasteners.
- H dimensions are sized to account for normal joist shrinkage. W dimensions are for dressed timber widths.
- Hangers may be welded to steel headers with weld size to match material thickness (approximate thickness shown) ¹

⁄8" for W, ³

⁄16" for WNP/WPU and 1
⁄4" for HW/HWU, by 1¹

⁄2" fillet welds located at each end of the top flange (see page 17 for welding information). Weld-on applications produce maximum allowable load listed. For uplift loads refer to technical bulletin T-WELDUPLFT (HWU and WPU hangers only).
- GLT/HGLT may be welded to steel headers, see page 104 for requirements.
- Hangers can support multi-ply carried members; the individual members must be secured together to work as a single unit before installation into the hanger.
- WM—two 16d duplex nails must be installed into the top flange and embedded into the grouted wall. Verify that the grouted wall can take the required fasteners specified in the table.
- Embed WM into block with a minimum of one course above and one course below the top flange with one #5 vertical rebar minimum 24" long in each cell. Minimum grout strength is 2000 psi.
OPTIONS: • Refer to technical bulletin T-SLOPEJST for information regarding load reductions on selected hangers which can be used without modification to support joists which have shallow slopes (≤³

⁄4:12).
- See Hanger Options, pages 233-243 for hanger modifications and associated load reductions.
- Some model configurations may differ from those shown. Contact Simpson Strong-Tie for details.
CODES: See page 12 for Code Reference Key Chart.
Model | Joist | Fasteners | Allowable Loads Header Type | Code
Width | Depth | Top | Face | Joist | (160) | LVL | PSL | LSL | DF/SP | SPF/ HF | I-Joist Masonry | | Ref. Uplift
W | 1¹ ⁄2 to 4 | 3¹ ⁄2 to 30 | 2-10dx1¹ ⁄2 | — | 2-10dx1¹ ⁄2 | — | 1635 | 1740 | — | 1600 | 1415 | — | — | 170
| 1¹ ⁄2 to 4 | 3¹ ⁄2 to 30 | 2-10d | — | 2-10dx1¹ ⁄2 | — | 2150 | 2020 | — | 2200 | 1435 | — | — | I10, F9, L14 1¹
| ⁄2 to 4 | 3¹ ⁄2 to 30 | 2-16d | — | 2-10dx1¹ ⁄2 | — | 2335 | 1950 | 2335 | 1765 | 1435 | — | —
WM | 1¹ ⁄2 to 7¹ ⁄2 | 3¹ ⁄2 to 30 | 2-16d DPLX | — | 2-10dx1¹ ⁄2 | — | MID-WALL INSTALLATION⁴ | | | | | | 4175 | L16
| 1¹ ⁄2 to 7¹ ⁄2 | ⁄2 to 30 3¹ | 2⁻¹ ⁄4x1³ ⁄4 Titens | — | 2-10dx1¹ ⁄2 | — | TOP OF WALL INSTALLATION | | | | | | 3380 | L11
WMU | ⁄2 1¹ ⁄2 to 7¹ | 9 to 28 | 2-16d DPLX | 4⁻¹ ⁄4x1³ ⁄4 Titens | 6-10dx1¹ ⁄2 | 625 | MID-WALL INSTALLATION⁴ | | | | | | 4175
| ⁄2 ⁄2 to 7¹ | 9 to 28 | 2⁻¹ ⁄4x1³ ⁄4 Titens | 4⁻¹ ⁄4x1³ ⁄4 Titens | 6-10dx1¹ ⁄2 | 545 | TOP OF WALL INSTALLATION | | | | | | 3380 | 170 1¹
WP/ WNP | 1¹ ⁄2 to 7¹ ⁄2 | 3¹ ⁄2 to 30 | 2-10dx1¹ ⁄2 | — | 2-10dx1¹ ⁄2 | — | 2865 | 3250 | — | 2500 | 2000 | 2030 | —
| 1¹ ⁄2 to 7¹ ⁄2 | 3¹ ⁄2 to 30 | 2-10d | — | 2-10dx1¹ ⁄2 | — | 2525 | 3250 | 3650 | 3255 | 2525 | — | — | I10, I19, F9, F18, L11, L14
| 1¹ ⁄2 to 7¹ ⁄2 | 3¹ ⁄2 to 30 | 2-16d | — | 2-10dx1¹ ⁄2 | — | 3635 | 3320 | 3650 | 3255 | 2600 | — | —
WPU/ WNPU | 1¹ ⁄2 to 5¹ ⁄2 | 7¹ ⁄4 to 18 | 3-16d | 4-16d | 6-10dx1¹ ⁄2 | 1095 | 4700 | 4880 | 3650 | 4165 | 4165 | — | —
| 1¹ ⁄2 to 5¹ ⁄2 | 18¹ ⁄2 to 28 | 3-16d | 4-16d | 6-10dx1¹ ⁄2 | 390 | 4700 | 4880 | 3650 | 4165 | 4165 | — | —
HW | 1¹ ⁄2 to 7¹ ⁄2 | 3¹ ⁄2 to 32 | 4-10d | — | 2-10dx1¹ ⁄2 | — | 3100 | 4000 | — | 5285 | 3100 | — | — | I10, I19, F9, F18, L11, L14
| 1¹ ⁄2 to 7¹ ⁄2 | 3¹ ⁄2 to 32 | 4-16d | — | 2-10dx1¹ ⁄2 | — | 5100 | 4000 | 4500 | 5285 | 3665 | — | —
HWU | 1¹ ⁄2 to 3¹ ⁄2 | 9 to 18 | 4-16d | 4-16d | 6-10dx1¹ ⁄2 | 1160 | 6335 | 5500 | 5535 | 6335 | 5415 | — | —
| 1¹ ⁄2 to 3¹ ⁄2 | 18¹ ⁄2 to 28 | 4-16d | 4-16d | 6-10dx1¹ ⁄2 | 965 | 6335 | 5500 | 5535 | 6335 | 5415 | — | —
| 1¹ ⁄2 to 3¹ ⁄2 | 28¹ ⁄2 to 32 | 4-16d | 4-16d | 8-10dx1¹ ⁄2 | 985 | 6335 | 5500 | 5535 | 6335 | 5415 | — | —
| 4¹ ⁄2 to 7 | 9 to 18 | 4-16d | 4-16d | 6-10dx1¹ ⁄2 | 1160 | 6000 | 5500 | 5535 | 6000 | 5415 | — | —
| 4¹ ⁄2 to 7 | 18¹ ⁄2 to 28 | 4-16d | 4-16d | 6-10dx1¹ ⁄2 | 965 | 6000 | 5500 | 5535 | 6000 | 5415 | — | —
| 4¹ ⁄2 to 7 | 28¹ ⁄2 to 32 | 4-16d | 4-16d | 8-10dx1¹ ⁄2 | 985 | 6000 | 5500 | 5535 | 6000 | 5415 | — | —

NAILER TABLE
The table indicates
the maximum allowable
loads for W, WNP and
HW hangers used on
wood nailers. Nailers
are wood members
attached to the top of
a steel I-beam, concrete
or masonry wall.
1. Uplift value for the
HWU hanger is for
depths ≤18" and are
for DF/SP values only.
Refer to uplift values
in table below for
taller depths.
2. Attachment of nailer
to supporting member
is the responsibility
of the Designer.
Model Nailer | | Top Flange Nailing | Uplift¹ (160) | Allowable Down Loads
DF/SP | SPF/HF | LSL
W | 2x | 2-10dx1¹ ⁄2 | — | 1600 | 1600 | —
| 2-2x | 2-10d | — | 1665 | 1665 | —
| 3x | 2-16dx2¹ ⁄2 | — | 1765 | — | —
| 4x | 2-10d | — | 2200 | — | —
WP and WNP | 2x | 2-10dx1¹ ⁄2 | — | 2525 | 2500 | 3375
| 2-2x | 2-10d | — | 3255 | 3255 | —
| 3x | 2-16dx2¹ ⁄2 | — | 3000 | 2510 | 3375
| 4x | 2-10d | — | 3255 | 3255 | —
WPU | 2-2x | 7-10d | 700 | 3255 | — | —
| 3x | 7-16dx2¹ ⁄2 | 970 | 3000 | — | —
| 4x | 7-16d | 1095 | 3255 | — | —
HW | 2-2x | 4-10d | — | 4860 | — | —
| 3x | 4-16dx2¹ ⁄2 | — | 4845 | — | —
| 4x | 4-16d | — | 5285 | — | —
HWU | 2-2x | 8-16dx2¹ ⁄2 | 710 | 5430 | — | —
| 3x | 8-16dx2¹ ⁄2 | 970 | 5430 | — | —
| 4x | 8-16d | 1160 | 5430 | — | —

Eased Edge
Flatten edge of header to
match top flange radius.

# 87 Solid Sawn Joist Hangers

# TOP FLANGE HANGERS – SOLID SAWN LUMBER (DF/SP)

Solid Sawn Joist Hangers

DON’T FEEL LIKE SIFTING THROUGH THIS TABLE? Visit www.strongtie.com/
software to learn more about our new Joist Hanger Selector software.

These products are available with additional corrosion protection. Additional products on
this page may also be available with this option, check with Simpson Strong-Tie for details.

Joist or Purlin Size | Model No. | Ga | Dimensions | Fasteners | DF/SP Allowable Loads | Installed Cost Index (ICI) | Code

W | H | B | TF | Header | Joist | (160) | Floor (100) | Snow (115) | Roof (125) | Ref. Uplift

SAWN LUMBER SIZES

2x4 | HU24TF | 12 | 1⁹ ⁄16 | 3⁷ ⁄16 | 2¹ ⁄4 | 2¹ ⁄2 | 6-16d | 2-10dx1¹ ⁄2 | 295 | 2090 | 2100 | 2100 | Lowest | I10, F9, L11
DBL 2x4 | HU24-2TF | 12 | 3¹ ⁄8 | 3⁷ ⁄16 | 2¹ ⁄2 | 2¹ ⁄2 | 8-16d | 2-10d | 375 | 2600 | 2600 | 2600 | Lowest
2x6 | JB26 | 18 | 1⁹ ⁄16 | 5³ ⁄8 | 1¹ ⁄2 | 1⁵ ⁄16 | 4-10d | 2 PRONG | — | 1040 | 1040 | 1040 | Lowest
LB26 | 14 | 1⁹ ⁄16 | 5³ ⁄8 | 1¹ ⁄2 | 1¹ ⁄2 | 4-16d | 2-10dx1¹ ⁄2 | 290 | 1380 | 1380 | 1380 | +117%
HU26TF | 12 | 1⁹ ⁄16 | 5³ ⁄8 | 2¹ ⁄4 | 2¹ ⁄2 | 10-16d | 4-10dx1¹ ⁄2 | 590 | 2275 | 2330 | 2335 | +568%
W26 | 12 | 1⁹ ⁄16 | 5³ ⁄8 | 2¹ ⁄2 | 2¹ ⁄2 | 2-10d | 2-10dx1¹ ⁄2 | — | 2200 | 2200 | 2200 | +890%
DBL 2x6 | HUS26-2TF | 14 | 3¹ ⁄8 | 5³ ⁄8 | 2 | 1³ ⁄4 | 6-16d | 4-16d | 1235 | 2820 | 3000 | 3000 | Lowest
WNP26-2 | 12 | 3¹ ⁄8 | 5³ ⁄8 | 2¹ ⁄2 | 2³ ⁄16 | 2-10d | 2-10d | — | 3255 | 3255 | 3255 | +33%
HU26-2TF | 12 | 3¹ ⁄8 | 5³ ⁄8 | 2¹ ⁄2 | 2¹ ⁄2 | 10-16d | 4-10d | 750 | 3725 | 3900 | 3900 | +87%
2x8 | JB28 | 18 | 1⁹ ⁄16 | 7¹ ⁄4 | 1¹ ⁄2 | 1⁵ ⁄16 | 4-10d | 2 PRONG | — | 1050 | 1050 | 1050 | Lowest
LB28 | 14 | 1⁹ ⁄16 | 7¹ ⁄4 | 1¹ ⁄2 | 1¹ ⁄2 | 4-16d | 2-10dx1¹ ⁄2 | 290 | 1270 | 1270 | 1270 | +98%
HU28TF | 12 | 1⁹ ⁄16 | 7¹ ⁄8 | 2¹ ⁄4 | 2¹ ⁄2 | 10-16d | 4-10dx1¹ ⁄2 | 590 | 2335 | 2335 | 2335 | +563%
W28 | 12 | 1⁹ ⁄16 | 7¹ ⁄8 | 2¹ ⁄2 | 2¹ ⁄2 | 2-10d | 2-10dx1¹ ⁄2 | — | 2200 | 2200 | 2200 | +570%
DBL 2x8 | HUS28-2TF | 14 | 3¹ ⁄8 | 7¹ ⁄4 | 2 | 1⁷ ⁄8 | 8-16d | 6-16d | 1550 | 3455 | 3720 | 3895 | Lowest
WNP28-2 | 12 | 3¹ ⁄8 | 7¹ ⁄8 | 2¹ ⁄2 | 2³ ⁄16 | 2-10d | 2-10d | — | 3255 | 3255 | 3255 | +16%
HU28-2TF | 12 | 3¹ ⁄8 | 7¹ ⁄8 | 2¹ ⁄2 | 2¹ ⁄2 | 12-16d | 4-10d | 750 | 3900 | 3900 | 3900 | +75%

LB210AZ | 14 | 1⁹ ⁄16 | 9³ ⁄16 | 2 | 1⁷ ⁄16 | 6-16d | 2-10dx1¹ ⁄2 | 380 | 1865 | 1865 | 1865 | — | 170
HU210TF | 12 | 1⁹ ⁄16 | 9¹ ⁄8 | 2¹ ⁄4 | 2¹ ⁄2 | 12-16d | 4-10dx1¹ ⁄2 | 590 | 2335 | 2335 | 2335 | +359% | I10, F9, L11
W210 | 12 | 1⁹ ⁄16 | 9¹ ⁄8 | 2¹ ⁄2 | 2¹ ⁄2 | 2-10d | 2-10dx1¹ ⁄2 | — | 2200 | 2200 | 2200 | +360%

DBL 2x10 | HUS210-2TF | 14 | 3¹ ⁄8 | 9¹ ⁄4 | 2 | 1¹ ⁄2 | 10-16d | 8-16d | 2590 | 3585 | 3925 | 4155 | Lowest

WNP210-2 | 12 | 3¹ ⁄8 | 9¹ ⁄8 | 2¹ ⁄2 | 2³ ⁄16 | 2-10d | 2-10d | — | 3255 | 3255 | 3255 | +9%
HU210-2TF | 12 | 3¹ ⁄8 | 9¹ ⁄8 | 2¹ ⁄2 | 2¹ ⁄2 | 14-16d | 6-10d | 1125 | 4170 | 4170 | 4170 | +67%

TPL 2x10 | HU210-3TF | 12 | 4¹¹⁄16 | 9¹ ⁄8 | 2¹ ⁄2 | 2¹ ⁄2 | 14-16d | 6-16d | 1325 | 4150 | 4150 | 4150 | Lowest
2x12 | JB212A | 18 | 1⁹ ⁄16 | 11¹ ⁄8 | 2 | 1⁷ ⁄16 | 6-16d | 2-10dx1¹ ⁄2 | 315 | 1685 | 1685 | 1685 | — | 160

LB212AZ | 14 | 1⁹ ⁄16 | 11¹ ⁄8 | 2 | 1⁷ ⁄16 | 6-16d | 2-10dx1¹ ⁄2 | 380 | 1865 | 1865 | 1865 | — | 170
W212 | 12 | 1⁹ ⁄16 | 11 | 2¹ ⁄2 | 2¹ ⁄2 | 2-10d | 2-10dx1¹ ⁄2 | — | 2200 | 2200 | 2200 | +317%
12 | 1⁹ ⁄16 | 11 | 2¹ ⁄4 | 2¹ ⁄2 | 14-16d | 6-10dx1¹ ⁄2 | 885 | 2335 | 2335 | 2335 | +339% | I10, F9, L11 HU212TF

C-C-2015 © 2015 SIMPSON STRONG-TIE COMPANY INC. PRINTED 12/14

DBL 2x12 | HUS212-2TF | 14 | 3¹ ⁄8 | 11¹ ⁄8 | 2 | 2¹ ⁄4 | 10-16d | 8-16d | 2000 | 4435 | 4535 | 4605 | Lowest | I10, F9

WNP212-2 | 12 | 3¹ ⁄8 | 11 | 2¹ ⁄2 | 2³ ⁄16 | 2-10d | 2-10d | — | 3255 | 3255 | 3255 | +12%
HU212-2TF | 12 | 3 ⁄8 | 11 | 2¹ ⁄2 | 2¹ ⁄2 | 16-16d | 6-10d | 1125 | 4325 | 4660 | 4880 | +48% | I10, F9, L11 ¹

TPL 2x12 | HU212-3TF | 12 | 4¹¹⁄16 | 11 | 2¹ ⁄2 | 2¹ ⁄2 | 16-16d | 6-16d | 1325 | 4550 | 4885 | 5105 | Lowest
2x14 | JB214A | 18 | 1⁹ ⁄16 | 13¹ ⁄8 | 2 | 1⁷ ⁄16 | 6-16d | 2-10dx1¹ ⁄2 | 315 | 1685 | 1685 | 1685 | — | 160

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

## GPR SCAN

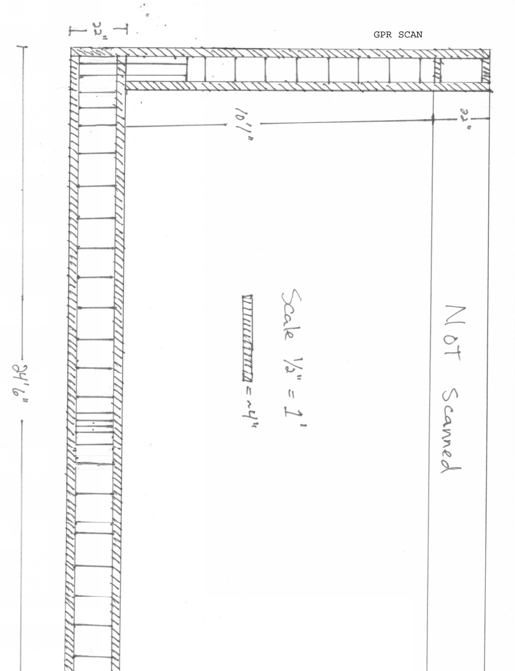
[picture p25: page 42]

## GPR SCAN





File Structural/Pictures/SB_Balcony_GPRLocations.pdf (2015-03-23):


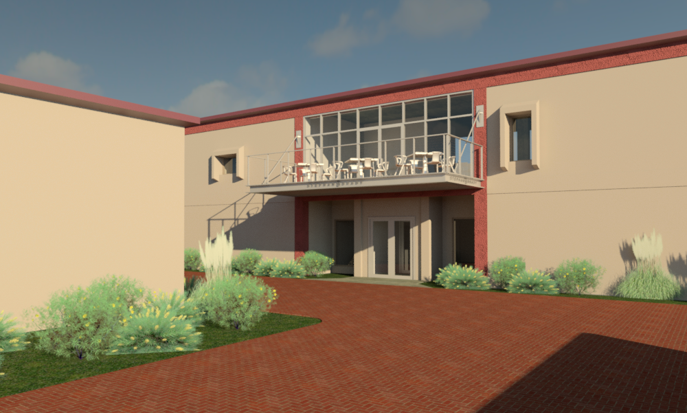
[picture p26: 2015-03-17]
Transfer/20150311_ updated design/SB_Balcony.rvt_2015-Mar-11_02-52-52PM-000_Perspective_-_Café_Balcony_-_inside_courtyard.png

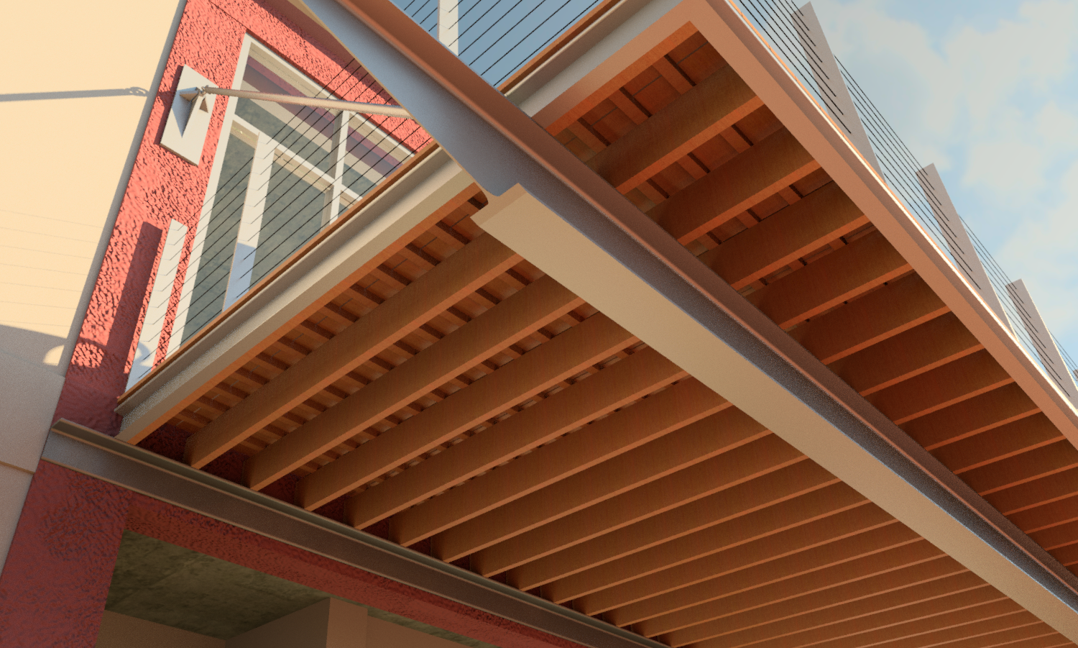
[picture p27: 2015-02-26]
Transfer/20150226 - Owner design review/SB_Balcony.rvt_2015-Feb-26_03-01-39PM-000_Perspective_-_Café_Balcony_-_under.png

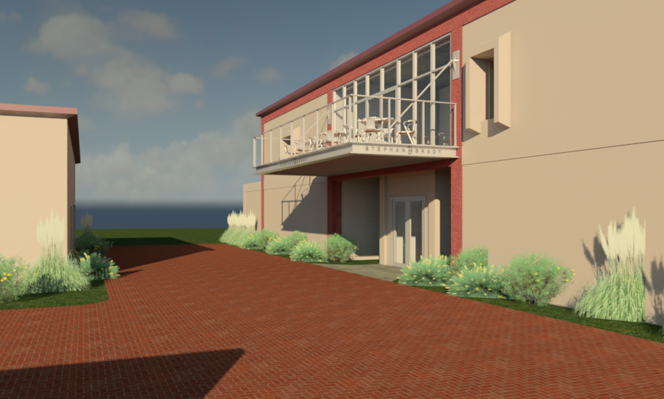
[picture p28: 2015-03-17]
Transfer/20150311_ updated design/SB_Balcony.rvt_2015-Mar-11_02-42-14PM-000_Perspective_-_Café_Balcony_-_from_Parking_Lot.png

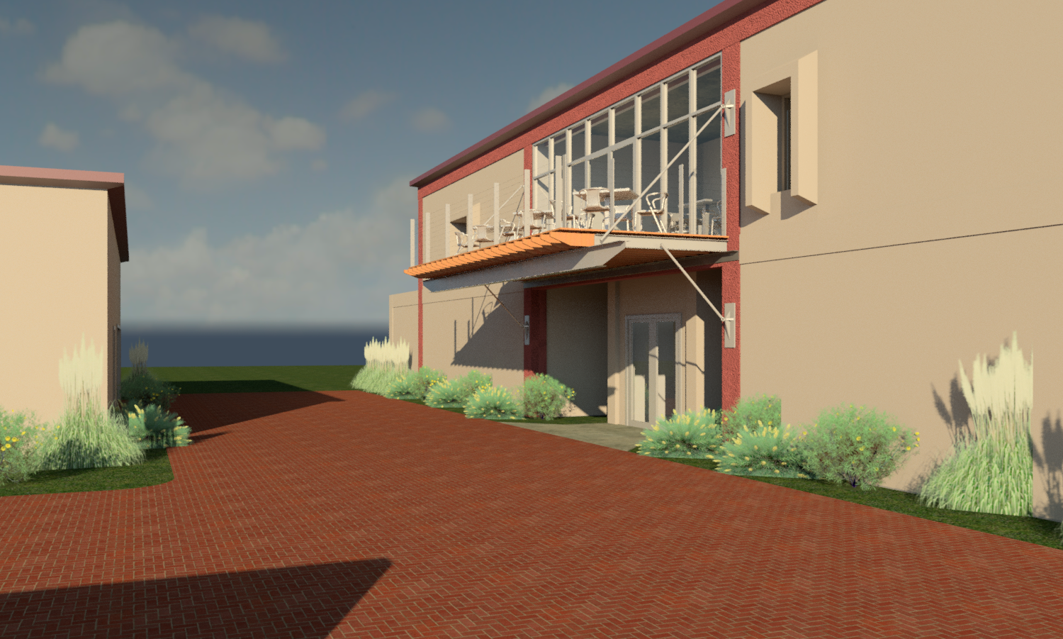
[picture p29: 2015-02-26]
Transfer/20150226 - Owner design review/SB_Balcony.rvt_2015-Feb-26_03-04-10PM-000_Perspective_-_Café_Balcony_-_from_Parking_Lot.png

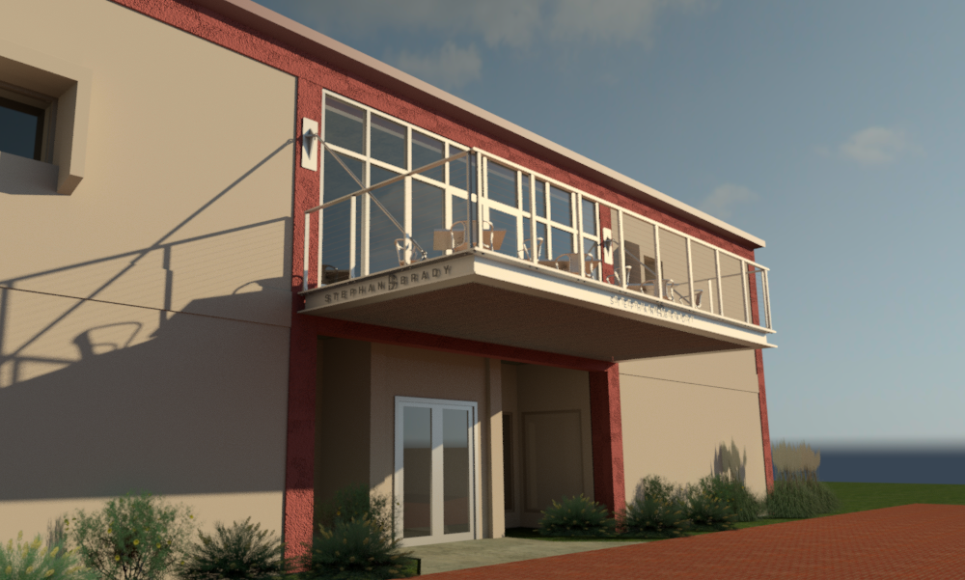
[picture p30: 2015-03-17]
Transfer/20150311_ updated design/SB_Balcony.rvt_2015-Mar-11_01-00-22PM-000_Perspective_-_Café_Balcony_-_Street_Approach_2.png

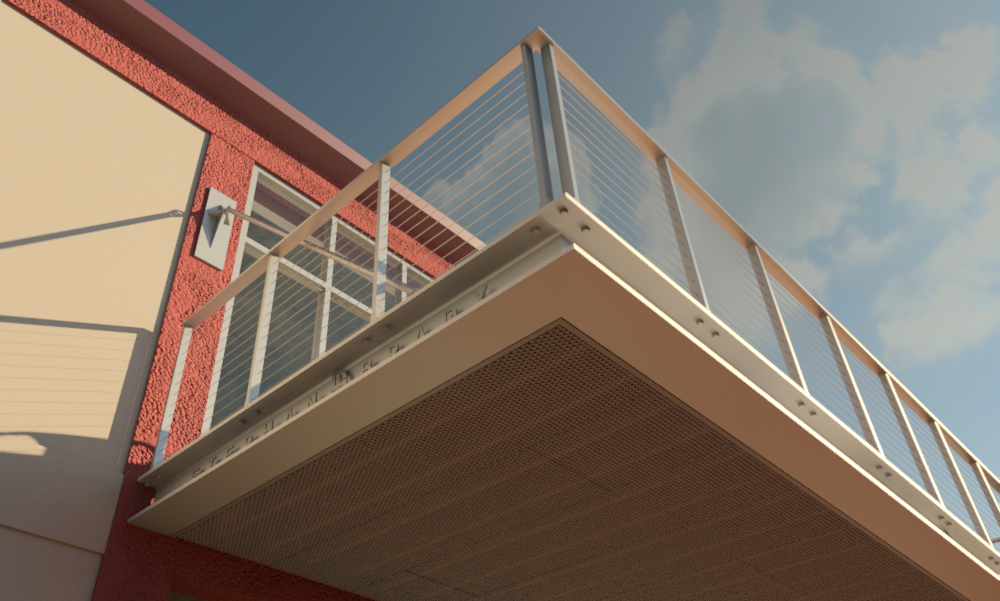
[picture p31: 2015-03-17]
Transfer/20150311_ updated design/SB_Balcony.rvt_2015-Mar-11_11-09-36AM-000_Perspective_-_Café_Balcony_-_under.png

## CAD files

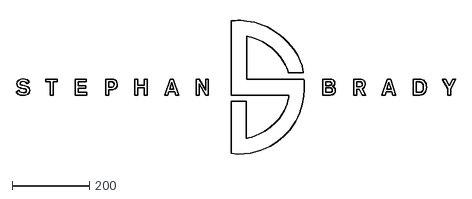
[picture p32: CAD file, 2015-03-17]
Model/source/S&B Large.dxf
1141.5 x 369.0

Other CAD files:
Model/source/S&B Large.dwg

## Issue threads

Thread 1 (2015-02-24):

Structural approach for new balcony

theoryshaw, 2015-02-24:
HI @stevenuecke, was wondering if you could do a sanity check on the proposed structural approach reflected in the following commit (models)...

https://github.com/OpeningDesign/Stephan_Brady_Balcony/commit/76d244834d136c28fb090bd23691c249f743c19d

Here's the existing conditions:
https://www.youtube.com/watch?v=7A2QnTbjuOA&feature=youtu.be

When you get a chance, please give me a call to discuss. Thanks Much.

stevenuecke, 2015-02-25:
I have attached some preliminary mark-ups for you to consider.

Thanks,

Steven Uecke

nTrive

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

stevenuecke, 2015-02-25:
Actually, I just uploaded it to the structural folder as ConceptMarkups_01.pdf

theoryshaw, 2015-02-25:
Thanks Steve for your comments.

Per your following comment...

> THIS PLACES A HUGE AMOUNT OF FORCE INTO THE WALL, AND THEN INTO THE DIAPHRAGM. IT IS LIKELY THAT WE WILL HAVE TO ADD FULL HEIGHT STEEL TUBES IN THE WALL TO TAKE THE LOAD.

Those anchor points are located at existing 16"x12" concrete columns.  Think we would still need full height steel tubes?

Although less desirable, perhaps we could do something like this to distribute the load?
https://www.dropbox.com/s/o9g1o87rx0gsca2/ScreenHunter_166%20Feb.%2025%2011.01.jpg?dl=0

> EXISTING HEADER? WE WILL PROBABLY NEED TO REINFORCE IT OR ADD A NEW ONE

Header is 18"Hx10"W concrete header.

> 2X10 @ 12" OR 16"

seems excessive.  they're only spanning ~7.5 feet.  Possible to do 2x8's 12" O.C.?

Do you think we can do without the uplift anchor points by using just the weight of the structure alone?

stevenuecke, 2015-02-25:
These comments were just made as a concept review - I didn't go into too much detail on it yet.
1. Concrete framing: Ok, great- do you have existing drawings for the concrete, so we can see the reinforcement?
2. Floor Joists: Ok, I was going based on the length of the member - I didn't realize it cantilevered that far. 2x8 at 16" is fine.
3. Steel beam: once I looked at the plan view, the span was shorter than I had estimated from the length of the member, so the W12X26 works fine.

theoryshaw, 2015-02-25:
okay, cool.  Yes, just a high level check is good for now.

Going to run the concepts by the owner.  If there's sign-off, we'll obviously do more detailed studies.

No drawing for this building, unfortunately.  Probably have to scan the concrete for reinforcing locations.

She's a pretty beefy structure--old military barracks by the airport.

Will keep you posted. Thx!

theoryshaw, 2015-03-17:
Hi @stevenuecke

Made a couple owner requested revisions since the last iteration  --> https://github.com/OpeningDesign/Stephan_Brady_Balcony/commit/9b51dd539c6e1435c7c9d723da14a6c2b4e95d7b

If we can, let's work concurrently on the Revit model via this: http://knowledge.autodesk.com/support/revit-products/downloads/caas/downloads/content/autodesk-a360-collaboration-for-revit-2015.html

I shared the A360 project with you.  You should be getting an invite via email.

Let me know if you're able to install R4C and if you're able to open the shared model.

Once you do, let's have a followup conversation.

Thanks!

stevenuecke, 2015-03-17:
I was able to install this, but I wasn't able to open the shared model - I couldn't see the model through the web browser either, my login says that there is no data in the A360 project.
Also, when I try to access the project in Revit, I get the following:
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

Have you been able to make it work?

theoryshaw, 2015-03-17:
That's unfortunate.  I was under the impression (the wrong one, it seems) that if one party had R4C that they could invite others.  It seems all team members accessing the shared model have to pay $100/month.  Seems like a crazy high price.

Anyways, we can do this 'old school', if you'd like.  Here's the latest Revit file --> https://github.com/OpeningDesign/Stephan_Brady_Balcony/commit/de610d945319c0300663edf4969cbb90aa02aeac

We can talk tomorrow, if that works for you.

stevenuecke, 2015-03-17:
Yes, I have synced the Documents, so whenever you want to discuss is fine. Is it time for the full structural design? Also, did you find out whether the owner is concerned at all with the existing structure?

theoryshaw, 2015-03-17:
Yes, time for full blown design.

Let's do 10am tomorrow, if that works for you.
Phone: 302.202.5900
Conference ID: 796-554-157
screensharing: https://join.me/ryanschultz

stevenuecke, 2015-03-17:
Ok, I'll be on the call

theoryshaw, 2015-03-23:
@stevenuecke when you get a chance, can you upload that sketch for suggested scan locations.  Thx.

stevenuecke, 2015-03-23:
Just posted it in the structural folder named as: SB_Balcony_GPRLocations.pdf

Closed 2015-06-01.

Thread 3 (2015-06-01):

Refining Balcony Structure...

theoryshaw, 2015-06-01:
Thanks @andyeck1 for your sketches [here](https://github.com/OpeningDesign/Stephan_Brady_Balcony/blob/d170d7ed04941e2bf4621dbcee7193211e02b96f/Transfer/20150527%20-%20sketches%20from%20ntrive/20150527%20-%20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).

I've incorporated your sketches/notes in the revised drawings [here](https://github.com/OpeningDesign/Stephan_Brady_Balcony/blob/4da96446167583eda3c7331d719f6464a38f06e8/Transfer/20150601%20-%20for%20ntrive%20comment/20150601%20-%20SB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).

As you'll see, i've tweaked your suggested appoach in conservative manner--mainly for aesthetic reasons. In general, could you please review?  Please let me know if you see any problems with this counter proposal.

I've also included additional questions/comments in red.

Thanks Much, Ryan

(ping @kraut34)

andyeck1, 2015-06-05:
@theoryshaw
we are working on the comments and we will have some markups for you on Monday.  We should have the calcs   ready for permit on Wednesday.

@KevinZinsmeister @avitro

kraut34, 2015-06-08:
Ryan,

Can I take this to Endres to have them get going on repricing their quote?

Toby Krause
Krause Custom Builders
920-285-6490

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

theoryshaw, 2015-06-08:
@kraut34 I would hold off until @andyeck1 addresses the few comments in markedup PDF mentioned above.

I also have to add a couple more annotations, etc., that will help Endres dial into an accurate estimate.

Thanks.

theoryshaw, 2015-06-08:
@andyeck1 Forgot to mention in that marked up PDF we'll need help sizing the 'plate angle' that will be welded to the backside of these beams...
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

Thanks.

KevinZinsmeister, 2015-06-09:
@theoryshaw For the balcony framing members, we can go with 2x10's @ 12" oc or 2x12's @ 16" oc.  Which would you prefer?

theoryshaw, 2015-06-09:
can we get away with 2x8's?  They are only spanning 10.5'

Plus with the W10x39's we don't have the cavity depth to hide a 2x10 or 2x12.

Thanks.

KevinZinsmeister, 2015-06-09:
We would need to specify select structural 2x8's to get the required moment capacity.  Keep in mind that the live load is 80 psf at the balcony which is higher than what typical wood construction sees.

For our reference, what is the thickness of the composite decking that is going to be used?

kraut34, 2015-06-09:
Would it be possible to double up the 2x8 framing. we could glue and screw
two of them together if that helps.
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

theoryshaw, 2015-06-09:
@kraut34 , sistering (2) 2x8's would be more cost effective than using structural grade 2x8's?

kraut34, 2015-06-09:
I wasn't sure if you could get fire retardent structural grade 2x8s easily.
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

theoryshaw, 2015-06-22:
@KevinZinsmeister, @andyeck1,

Incorporated your comments into the following revised drawing..

https://github.com/OpeningDesign/Stephan_Brady_Balcony/blob/b6e5b3e696d79bb49d253be662d24f24456d4601/Transfer/20150622%20-%20GC%20and%20ntrive%20review/20150622%20-%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

Can you please review?

Also, please send along structural calculations as well.  Would like to submit for permit tomorrow or Wednesday if everything goes well.

Thanks Much, Ryan

andyeck1, 2015-06-23:
Uploaded calcs.

Thank you,

Andy Eck, SE, PE

Ntrive – Structural Engineering

Office Number: 630-318-1725 x701

Mobile Number: 630-886-4688

280 Shuman Blvd, Suite 270

Naperville, IL  60563

-Check out our website at:  <http://ntrive.com/> ntrive.com

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

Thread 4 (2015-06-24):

Hanger condition at front edge of balcony

theoryshaw, 2015-06-24:
@andyeck1,

Per this detail, in your structural calculations...

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

To avoid seeing the 'hanger' exposed to the top side of the deck, is it possible to do something like the following instead.

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

Thanks.
ping (@kraut34)

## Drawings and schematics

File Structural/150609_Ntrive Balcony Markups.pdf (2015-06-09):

3 2

A

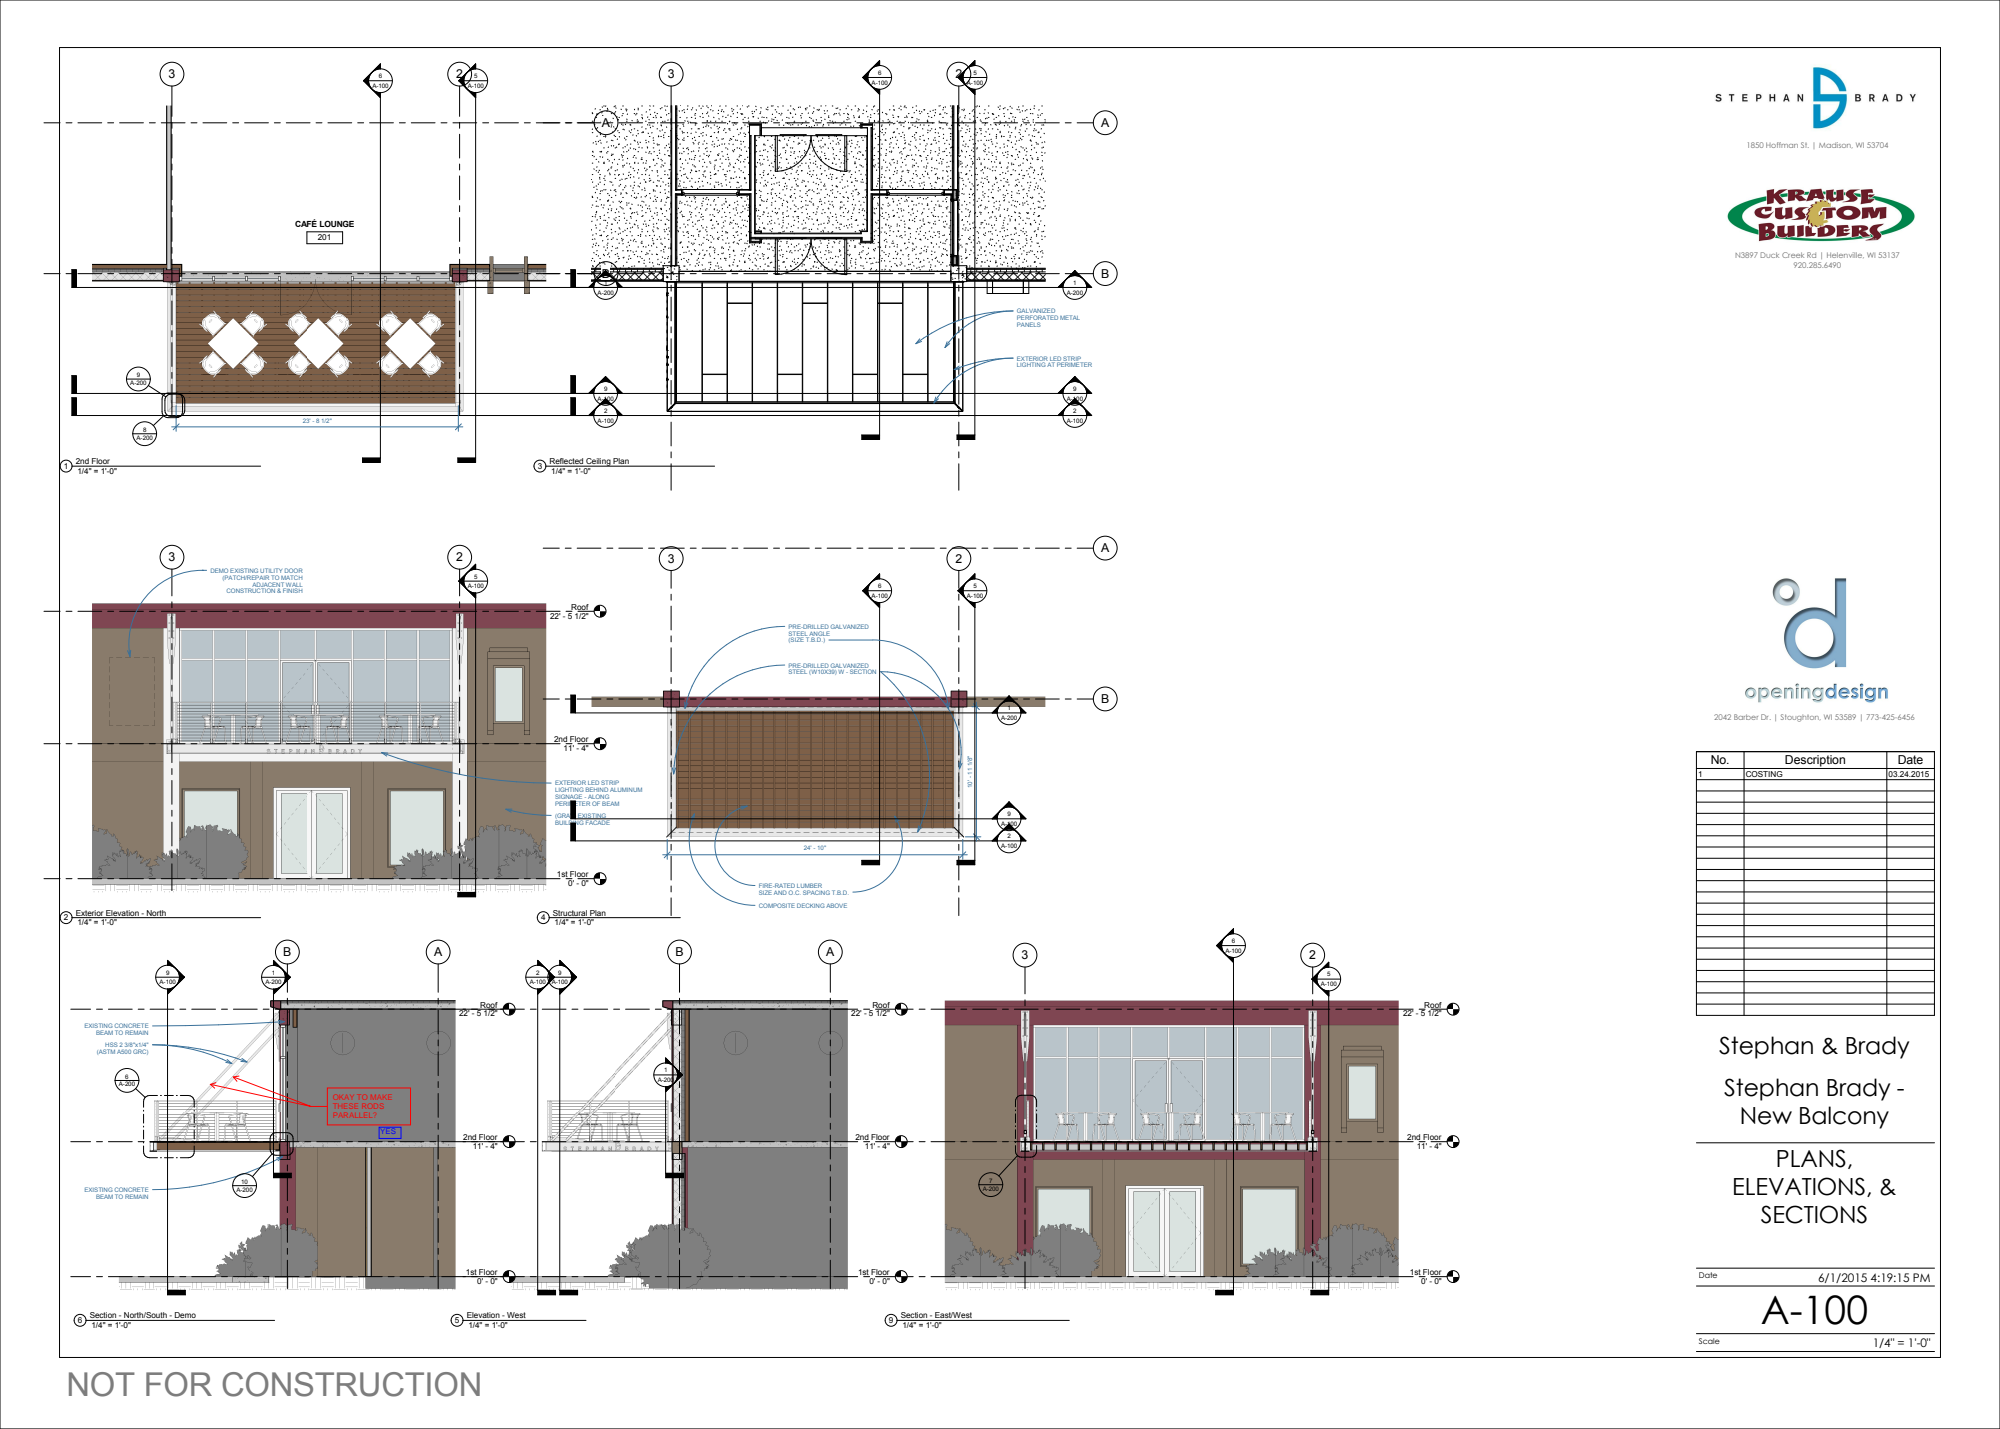
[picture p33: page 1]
CAFÉ LOUNGE; 1st Floor 0' - 0"; 2nd Floor 11' - 4"; Roof 22' - 5 1/2"; (GRAY) EXISTING BUILDING FACADE; ADJACENT WALL CONSTRUCTION & FINISH; HSS 2 3/8"x1/4" (ASTM A500 GRC); GALVANIZED PERFORATED METAL PANELS; Scale; Date; PLANS, ELEVATIONS, & SECTIONS; Stephan & Brady; Stephan Brady - New Balcony; 2nd Floor; Structural Plan; Elevation - West; Section - East/West; Description; COSTING

1850 Hoffman St. | Madison, WI 53704

N3897 Duck Creek Rd | Helenville, WI 53137

EXTERIOR LED STRIP
LIGHTING AT PERIMETER

Reflected Ceiling Plan

DEMO EXISTING UTILITY DOOR
(PATCH/REPAIR TO MATCH

PRE-DRILLED GALVANIZED
STEEL ANGLE
(SIZE T.B.D.)

STEEL (W10X39) W - SECTION

2042 Barber Dr. | Stoughton, WI 53589 | 773-425-6456

LIGHTING BEHIND ALUMINUM
SIGNAGE - ALONG
PERIMETER OF BEAM

FIRE-RATED LUMBER
SIZE AND O.C. SPACING T.B.D.

COMPOSITE DECKING ABOVE

Exterior Elevation - North

EXISTING CONCRETE
BEAM TO REMAIN

Section - North/South - Demo
NOT FOR CONSTRUCTION

212

213

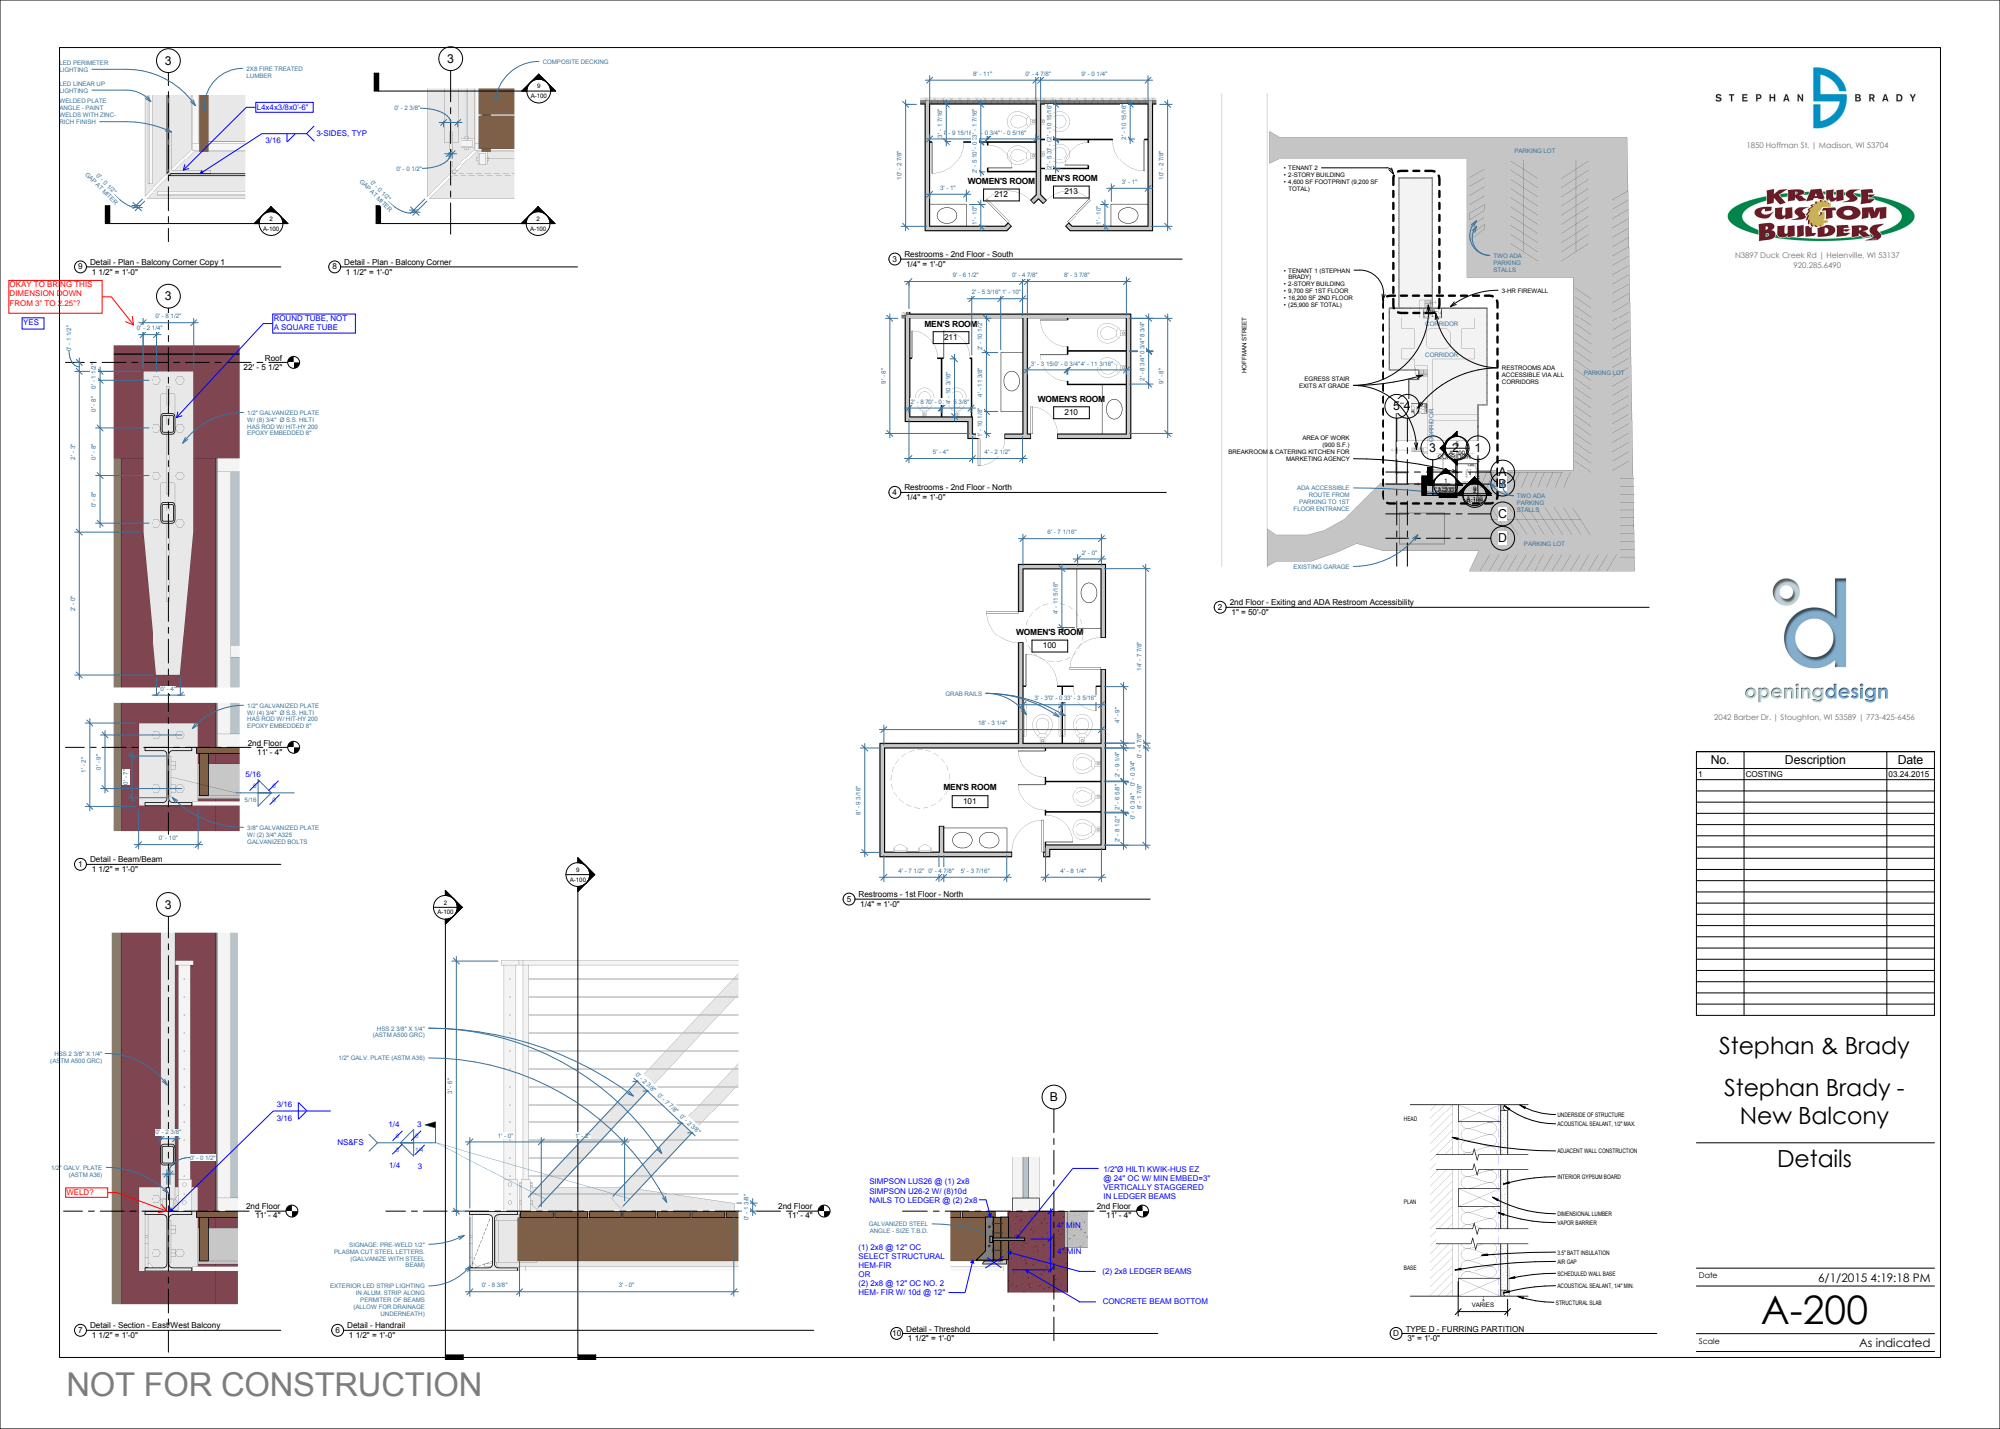
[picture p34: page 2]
STRUCTURAL SLAB; BASE; PLAN; HEAD; VARIES; DIMENSIONAL LUMBER; VAPOR BARRIER; AIR GAP; 3.5" BATT INSULATION; • TENANT 1 (STEPHAN BRADY) • 2-STORY BUILDING • 9,700 SF 1ST FLOOR • 16,200 SF 2ND FLOOR • (25,900 SF TOTAL); CORRIDOR; MARKETING AGENCY; PARKING LOT; TWO ADA PARKING STALLS; ADA ACCESSIBLE ROUTE FROM PARKING TO 1ST FLOOR ENTRANCE; HOFFMAN STREET; EXISTING GARAGE; 3-HR FIREWALL; WOMEN'S ROOM; MEN'S ROOM; GRAB RAILS; 2nd Floor 11' - 4"; Roof 22' - 5 1/2"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

LED LINEAR UP
LIGHTING
WELDED PLATE
ANGLE - PAINT
WELDS WITH ZINC-
RICH FINISH

1850 Hoffman St. | Madison, WI 53704

• TENANT 2
• 2-STORY BUILDING
• 4,600 SF FOOTPRINT (9,200 SF
TOTAL)

GAP AT MITER

N3897 Duck Creek Rd | Helenville, WI 53137

Detail - Plan - Balcony Corner Copy 1

Detail - Plan - Balcony Corner

RESTROOMS ADA
ACCESSIBLE VIA ALL
CORRIDORS

EGRESS STAIR
EXITS AT GRADE

1/2" GALVANIZED PLATE
W/ (8) 3/4" Ø S.S. HILTI
HAS ROD W/ HIT-HY 200
EPOXY EMBEDDED 8"

AREA OF WORK

BREAKROOM & CATERING KITCHEN FOR

2nd Floor - Exiting and ADA Restroom Accessibility

W/ (4) 3/4" Ø S.S. HILTI

2042 Barber Dr. | Stoughton, WI 53589 | 773-425-6456

No. | Description | Date

1 | COSTING | 03.24.2015

Detail - Beam/Beam

1/2" GALV. PLATE (ASTM A36)

UNDERSIDE OF STRUCTURE
ACOUSTICAL SEALANT, 1/2" MAX.

ADJACENT WALL CONSTRUCTION

INTERIOR GYPSUM BOARD

SIGNAGE: PRE-WELD 1/2"
PLASMA CUT STEEL LETTERS.
(GALVANIZE WITH STEEL

SCHEDULED WALL BASE

EXTERIOR LED STRIP LIGHTING

ACOUSTICAL SEALANT, 1/4" MIN.

IN ALUM. STRIP ALONG
PERMITER OF BEAMS
(ALLOW FOR DRAINAGE

Detail - Section - East/West Balcony

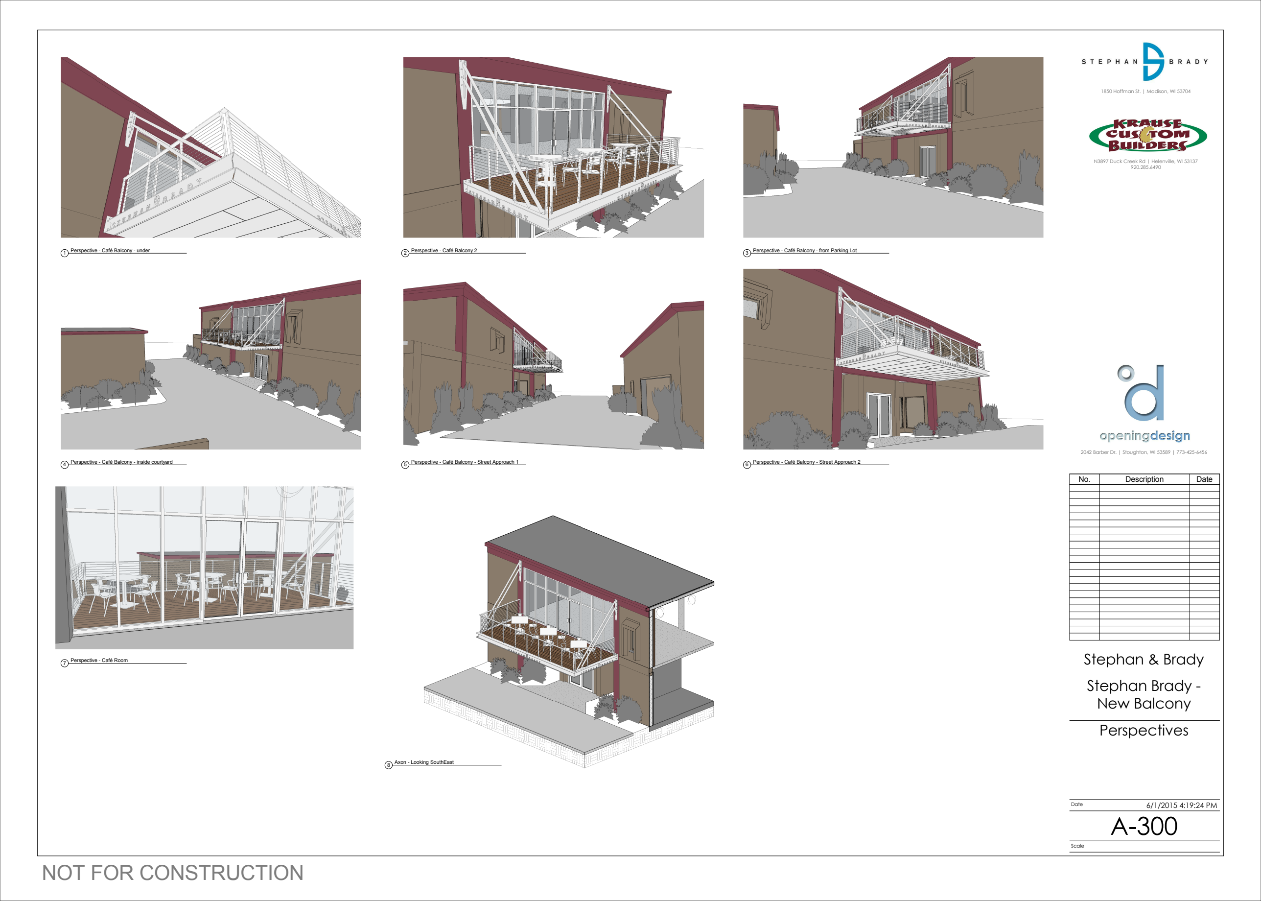
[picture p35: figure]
Date; 1850 Hoffman St. | Madison, WI 53704; Perspectives; Stephan & Brady; Stephan Brady - New Balcony; Perspective - Café Balcony - under; Perspective - Café Balcony 2; Perspective - Café Room; Axon - Looking SouthEast; Description

### 2042 Barber Dr. | Stoughton, WI 53589 | 773-425-6456

### N3897 Duck Creek Rd | Helenville, WI 53137

## Perspective - Café Balcony - from Parking Lot

Perspective - Café Balcony - inside courtyard | 5
Perspective - Café Balcony - Street Approach 1 | 6

## Perspective - Café Balcony - Street Approach 2
